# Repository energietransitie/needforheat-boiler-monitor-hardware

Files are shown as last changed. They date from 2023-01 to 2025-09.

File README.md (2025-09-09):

# NeedForHeat Boiler Monitor hardware <!-- omit in toc -->

This repository contains the open hardware design files for the NeedForHeat Boiler Monitor hardware, which consists of PCB and 3D printable pipeclamps for:

* Boiler-BASE module for the on the back of an [M5Stack CoreInk](https://docs.m5stack.com/en/core/coreink) device;
* Thermostat Cable Splitter module, which is inserted by the subject in the signal path between boiler and thermostat;
* Two pipe clamps with temperature sensors that can be clipped on the supply and return pipes that carry hot water from the boiler to the radiators and returning from the radiators.

This integrated device can:
* monitor OpenTherm signals between boiler and thermostat, similar to the [Twomes OpenTherm monitor](https://github.com/energietransitie/twomes-opentherm-monitor-hardware);
* monitor on/off signals between boiler and thermostat that do not adhere to the OpenTherm standard;
* monitor with supply and return water temperatures, similar to the [Twomes Temperature Monitor Hardware](https://github.com/energietransitie/twomes-temp-monitor-hardware).

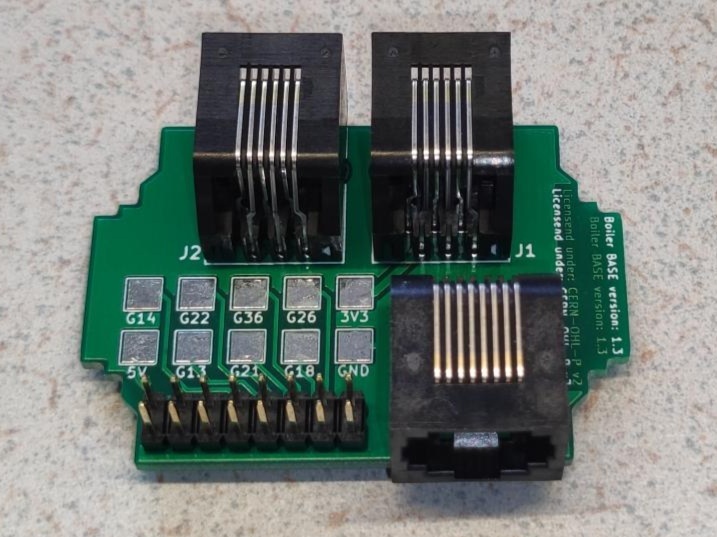
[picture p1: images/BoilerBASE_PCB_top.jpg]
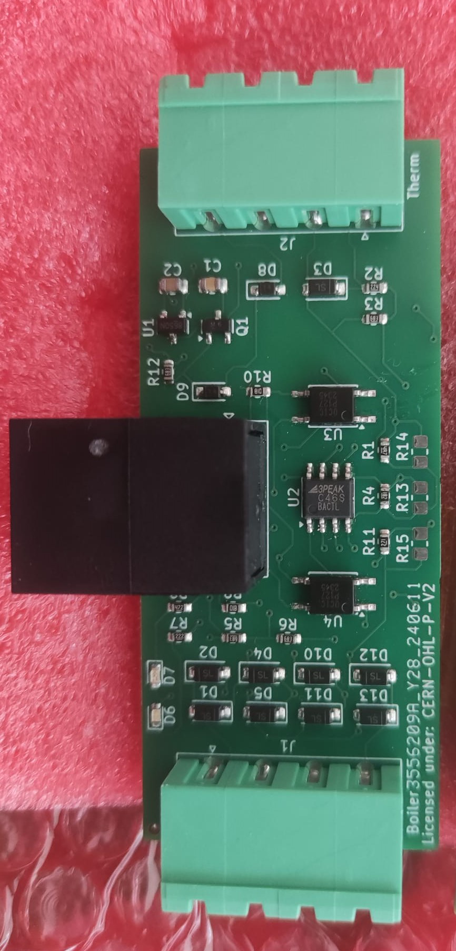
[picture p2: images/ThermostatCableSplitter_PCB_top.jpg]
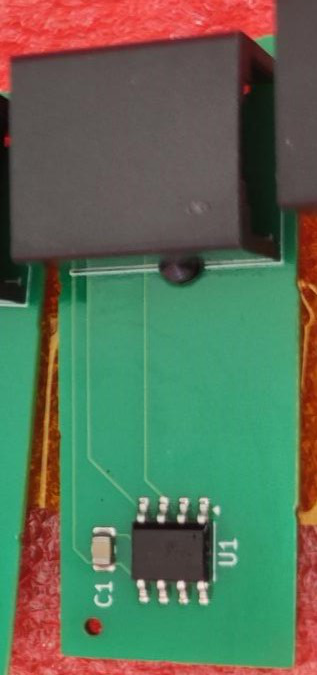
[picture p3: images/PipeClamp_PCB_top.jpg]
  

<!-- it would be better to have an image of the entire solution, including cables, like the assignment presentation -->

## Table of contents <!-- omit in toc -->
- [General info](#general-info)
- [Producing](#producing)
  - [Printed Circuit Board](#printed-circuit-board)
  - [Enclosures](#enclosures)
- [Deploying](#deploying)
  - [Cost](#cost)
  - [Connecting](#connecting)
  - [Disconnecting](#disconnecting)
- [Developing](#developing)
  - [Printed Circuit Board](#printed-circuit-board-1)
  - [Enclosures](#enclosures-1)
- [Features](#features)
- [Status](#status)
- [License](#license)
- [Citation](#citation)
- [Credits](#credits)

## General info
This repository contains the open hardware designs files and production files for the NeedForHeat Boiler Monitor. It also includes a `docs` folder with recent printouts of:
* BoilerBASE: [schematics](./docs/BoilerBase-sch.pdf) and [PCB layout](./docs/BoilerBase-pcb.pdf);
* Thermostat Cable Splitter:[schematics](./docs/ThermostatCableSplitter-sch.pdf) and [PCB layout](./docs/ThermostatCableSplitter-pcb.pdf);
* Pipe Clamps: [schematics](./docs/PipeClamp-pcb.pdf) and [PCB layout](./docs/PipeClamp-pcb.pdf).

The splitter features a 4 wire pluggable screw terminal on each side in which the cables can be connected to in almost any order.

The associated firmware that you need to run on this device was not yet implemented. I will be a combination of:
* [needforheat-generic-firmware](https://github.com/energietransitie/needforheat-generic-firmware) compiled with `env:M5STACK_COREINK`
* [twomes-opentherm-monitor-firmware](https://github.com/energietransitie/twomes-opentherm-monitor-firmware) 
* [twomes-boiler-base-firmware](https://github.com/energietransitie/twomes-boiler-base-firmware).

## Producing

### Printed Circuit Board
To manufacture the printed circuit board you can use various PCB services. 

The folder [pcb production](./pcb) includes all exported files needed to have the PCBs manufactured by [JLCPCB](https://www.jlcpcb.com). Upload a [zipped gerber file](./pcb/Gerber) to the [JLCPCB quote page](https://cart.jlcpcb.com/quote), select the amount of PCBs and a colour for the silkscreen. All other options can be left on default.

If you do not want to solder components on the PCB yourself, select `PCB assembly` and JLCPCB will do it for you (even for through-hole components if you so desire). This will take you to a page where the BOM and POS file can be uploaded. Use the files in [BOM-CPL](./pcb/BOM-CPL). 

JLCPCB provides detailed steps on their website to select component assembly, including wave soldering. For wave soldering or through-hole component assembly, specify this requirement when uploading your BOM and POS files. 

In the table below, you will find the files per PCB.

| PCB | zipped gerber | BOM | CPL | Components that do not need to be placed |
| --- | --- | --- | --- | --- |
| BoilerBASE | [GERBER-BoilerBASE.zip](pcb\BoilerBASE\jlcpcb\GERBER-BoilerBASE.zip) | [BOM-BoilerBASE.csv](pcb\BoilerBASE\jlcpcb\BoilerBASE\BOM-BoilerBASE.csv) | [BOM-BoilerBASE.csv](pcb\BoilerBASE\jlcpcb\BoilerBASE\CPL-BoilerBASE.csv) | |
| Thermostat Cable Splitter | [GERBER-ThermostatCableSplitter.zip](pcb\ThermostatCableSplitter\jlcpcb\GERBER-ThermostatCableSplitter.zip) | [BOM-ThermostatCableSplitter.csv](pcb\ThermostatCableSplitter\jlcpcb\ThermostatCableSplitter\BOM-ThermostatCableSplitter.csv) | [CPL-ThermostatCableSplitter.csv](pcb\jlcpcb\ThermostatCableSplitter\CPL-ThermostatCableSplitter.csv) | `R13`, `R14`, `R15` |
| Pipe Clamps | [GERBER-PipeClamp.zip](pcb\PipeClamp\jlcpcb\GERBER-PipeClamp.zip) | [BOM-PipeClamp.csv](pcb\PipeClamp\jlcpcb\Splitter\BOM-PipeClamp.csv) | [CPL-PipeClamp.csv](pcb\jlcpcb\Splitter\CPL-PipeClamp.csv) | |

### Enclosures

To manufacure the pipe clamps you can use your own 3D printer or use a 3D printing service. 

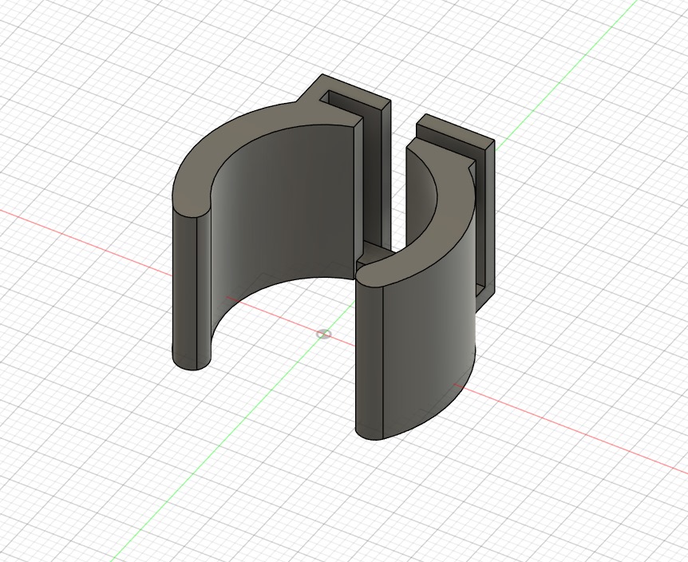
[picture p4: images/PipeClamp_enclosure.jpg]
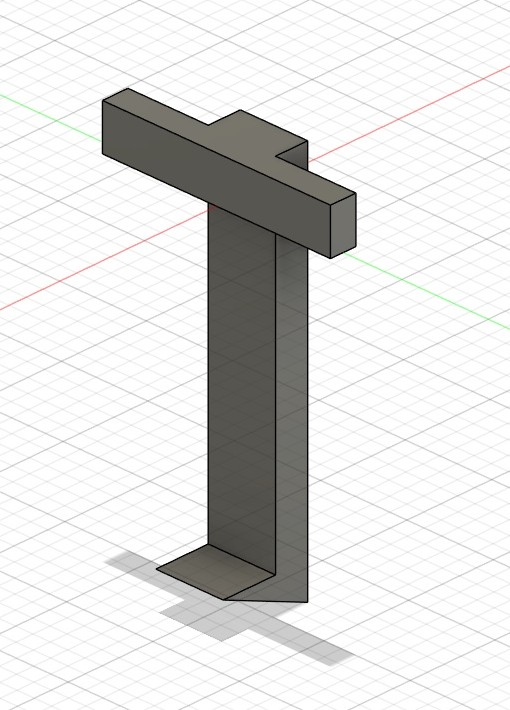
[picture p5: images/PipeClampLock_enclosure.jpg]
 

The folder [enclosure](./enclosure) contains exported STL files for:
* [Boiler-BASE enclosure](./enclosure/BoilerBASE/fabrication/BoilerBase.STL);
* [Pipe Clamp enclosure](./enclosure/PipeClamp/fabrication/PipeClamp.stl) and [Pipe Clamp enclosure locks](./enclosure/PipeClamp/fabrication/PipeClamp_lock.stl). 
 
The STL files can be imported into any slicer and turned into G-Code for a 3D printer.

We do not yet have designs for the Thermostata Cable Splitter.

## Deploying

### Cost
To deploy the NeedForHeat Boiler Module to a home, you need all hardware listed below. Prices indicate price per Boiler Monitor, based on ordering enough hardware for 10 Boiler Monitors, June 2024 including 21% VAT and shipping to an address in the Netherlands.

| # | Item | Supplier | Price per Unit | Subtotal | Shipping | Total |
| --- | --- | --- | ---: | ---: | ---: | ---: |
| 1 | BoilerBASE PCB | | €2.38 | €2.38 | €2.38 | €4,79 |
| 1 | BoilerBASE Enclosure | JLCPCB | €1.23 | €1.23 | €2.38 | €3.60 |
| 1 | Thermostat Cable Splitter PCB[^1] | JLCPCB | €5.02 | €5.02 | €3.23 | €8.25 |
| 1 | Thermostat Cable Splitter enclosure | | €2.38 | €2.38 | €2.38 | €4,79 |
| 2 | [Pluggable Terminal Blocks (5.08 mm. 4 ways)](https://nl.farnell.com/camdenboss/ctb9209-4/terminal-block-pluggable-4pos/dp/2493644) | | €1.15 | €2.30 | €1.82 | €3.12 |
| 2 | Pipe Clamp PCB | JLCPCB | €3.41 | €6.81 | €2.30 | €9.11 |
| 1 | Pipe Clamp enclosure | JLCPCB | €1.00 | €2.00 | €2.38 | €4.38 |
| 4 | [LEGO pen with friction](https://www.blokjeskoning.nl/product/pen-stroef-pen-stroef-zwart/) | Blokjeskoning | €0.03 | €0.12 | €0.30 | €0.42 |
| 1 | [M5Stack CoreInk](https://www.tinytronics.nl/nl/platformen-en-systemen/m5stack/e-paper/m5stack-m5core-ink-met-1.54-inch-e-paper-e-ink-display-esp32) | TinyTronics | €43.00 | €43.00 | €0.00 | €43.00 |
| 2 | [RJ12 cable (male-male; 6P6C; straight; 1 m)](https://www.allekabels.nl/rj12-kabel/7400/1181351/telefoonkabel-rj12.html) | AlleKabels | €3.08 | €6.16 | €0.13 | €6.29 |
| 1 | [RJ45 cable (male-male; 8P8C; straight; 1 m)](https://www.allekabels.nl/cat5e-kabel/15545/1098185/uutp-kabel-cat-5e.html) | AlleKabels | €1.29 | €1.29 | €0.13 | €1.42 |
| 1 | [USB-A 230V charger + USB-A to USB-C cable](https://www.allekabels.nl/usb-oplader/4508/3636716/usb-a-oplader-usb-c-kabel.html) | AlleKabels | €14.95 | €14.95 | €0.13 | €15.08 |
| | **TOTAL** | | | **€87.64** | **€17.46** | **€107.65** |

[^1]: Only the Thermostat Cable Splitter remains at the home of the user; the rest can be sent back after the measurement period.

### Connecting

Assuming that the PCBs are fully assembled, the devices have an enclosure, and the device has been programmed with the [needforheat-p1-reader-firmware](https://github.com/energietransitie/needforheat-p1-reader-firmware), you can proceed and connect the device as follows:

Tools needed;
- Screwdriver (flat head, 3 mm)
- Wire cutter
- Wire stripper

Steps:
1. **Unplug the power**
   - Unplug the boiler and thermostat from power outlets.

2. **Connect the Boiler Monitor**
   1. Cut the signal cable between the boiler and thermostat within 1.5 meters of a power outlet.
   2. Strip 2 cm of the outer sheath and 0.5 cm of insulation from each wire.
   3. Insert wires into the green pluggable screw terminal connectors and tighten screws.
   4. Attach connectors to the Thermostat Cable Splitter (boiler side: connector `J2` on the PCB and `CV` on the enclosure, thermostat side: connector `J1` on the PCB and  `T` on the enclosure).
   5. Connect the BoilerBASE to the M5Stack CoreInk MI-BUS using the 2x8 male pin header.
   6. Use an ethernet cable (RJ45) to connect the Thermostat Cable Splitter (connector `J3` on the PCB) to the BoilerBASE (connector `J3` on the PCB).
   7. Power the M5Coreink+BoilerBASE via USB-C.
   8. Insert PipeClamp PCBs into enclosures and secure with locking pins.
   9. Use cables (RJ12) to connect the BoilerBASE (connector `J1` and `J2` on the PCB; order does not matter) to the PipeClamps (connector `J1` on the PCB).
   10. Attach the M5Coreink+BoilerBASE to the boiler with its magnetic back on a flat metal surface of the boiler.
   11. Check LEDs on the Thermostat Cable Splitter; if not blinking, switch wires 1 & 2 or 3 & 4 in the pluggable screw connector on the thermostat side.

3. **Plug the power back in**
   - Reconnect the boiler and thermostat to power outlets.

### Disconnecting

After the measurement period, the user only needs to unplug the RJ45 cable from the Thermostat Cable Splitter, which can remain connected with the thermostat cable in the user's home. The rest can be sent back and re-used in other homes. 

## Developing

### Printed Circuit Board

To change the hardware design of the PCBs, you need:
* [KiCad version 8.0.0 or later](https://www.kicad.org/download/) installed to change te PCB design. 

The KiCad source files of the PCB can be found in subfolders of the folder [pcb](./pcb):
* [BoilerBASE](./pcb/BoilerBASE/)
* [ThermostatCableSplitter](./pcb/ThermostatCableSplitter/)
* [PipeClamp](./pcb/PipeClamp/)

To convert the PCBs into a format suitable for fabrication, consult the webpage of your PCB manufacturer of choice. For example, see the [JLCPCB guide on how to export Gerbers](https://support.jlcpcb.com/article/149-how-to-generate-gerber-and-drill-files-in-kicad) and the  [JLCPCB guide how to export the BOM and POS files](https://support.jlcpcb.com/article/84-how-to-generate-the-bom-and-centroid-file-from-kicad). You may also use a KiCad plug-in for this purpose such as [kicad-jlcpcb-tools](https://github.com/Bouni/kicad-jlcpcb-tools).

### Enclosures
To change the hardware design of an enclosure, you need either:
* [Autodesk Fusion 360]([https://www.kicad.org/download/](https://www.autodesk.com/products/fusion-360/personal)) installed (Autodesk provides 30 day free trials and [free one-year educational access](https://www.autodesk.com/education/edu-software/overview?sorting=featured&filters=individual) to its products and services for eligible students, teachers and research staff); 
* or [FreeCAD](https://www.freecadweb.org/), an open source alternative.

The source files of the enclosures can be found in subfolders of the folder [enclosure](./enclosure):
* [BoilerBASE](./enclosure/BoilerBASE)
* ThermostatCableSplitter (*We do not yet have a design for this enclosure*)
* [PipeClamp](./enclosure/PipeClamp/)

## Features
The  NeedForHeat Boiler Monitor features the follwoing main hardware components:
- [x] Thermostat Cable Splitter PCB with 4-wire pluggable screw terminals and circuit to monitor OpenTherm communication, including LEDs and optocouplers;
- [x] Circuit in the Thermostat Cable Splitter that allows (mostly) order agnostic connection of the 4 wires per pluggable screw connector (see also [connecting the devices](#connecting-the-devices));
- [x] Pipe Clamp PCB to measure temperatures from the supply and return pipes below the boiler.
- [x] Pipe Clamp enclosures, which can be 3D printed as a clamp that presses the temperature sensors agains a water pipe below a heating boiler and provide a  locking mechanism the prevent the PCB from falling out.

To-do:
- Thermostat Cable Splitter
  - [ ] Reconsider the choice of pluggable screw connectors: reversible? lever-operated (e.g., [WAGO PCB terminal block](https://www.wago.com/global/c/pcb-terminal-blocks-and-pluggable-connectors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))?
  - [ ] Redesign the thermostat side such that the user can mount the wires truly in any order.
  - [ ] Design an enclosure.
* BoilerBASE
  - [ ] Add an 868 MHz SMD transceiver chip to enable monitoring of wireless thermostats.
  - [ ] Add connectors to BOM and CPL files and repair rotation errors to enable through-hole soldering by JLCPC.
  - [ ] Evaluate relocating the 2x8 pin header from the bottom side to the top side of the PCB to reduce JLCPCB manufacturing costs. 
  - [ ] Improve BOM and CPL for JLCPCB through hole assembly. 
  - [ ] Design an enclosure that adds multiple mounting options
    - [ ] room to embed permanent magnets to make it stick to flat metallic surfaces of boilers;
    - [ ] a tie wrap hole.
* Pipe Clamps
  - [ ] Redesign 3D printed enclosures to ensure strength and durability.

## Status
Project is:  _in_progress_

## License
The hardware designs in this repository are available under the [CERN-OHL-P v2 license](./LICENSE), Copyright 2024 [Research group Energy Transition, Windesheim University of Applied Sciences](https://windesheim.nl/energietransitie)

## Citation

If you use this repository in your research or work, please cite the following pre-print, which describes the overall NeedForHeat DataGear system of which this repository is a part:

> Ter Hofte, H., & van Ravenzwaaij, N. (2025). *NeedForHeat DataGear: An Open Monitoring System to Accelerate the Residential Heating Transition*. arXiv preprint arXiv:2509.06927. https://doi.org/10.48550/arXiv.2509.06927

**Note:** This is a pre-print submitted on 8 Sep 2025 and has not yet been peer-reviewed. For the full paper, see [https://arxiv.org/abs/2509.06927](https://arxiv.org/abs/2509.06927).

## Credits
This hardware is a collaborative effort of:
* Bram Busch · [@BlueRisen](https://github.com/BlueRisen)
* Daan Tellegen · [@D-Tellegen](https://github.com/D-Tellegen)

Earlier versions of this open hardware were designed by:
* Huub Buter · [@h-buter](https://github.com/h-buter>)
* Mirjam van Wee
* Kees Fokker
  
Product owners:
* Henri ter Hofte · [@henriterhofte](https://github.com/henriterhofte)
* Marco Winkelman · [@MarcoW71](https://github.com/MarcoW71)

We use and gratefully acknowlegde the efforts of the makers of the following designs:

* [Twomes OpenTherm monitor](https://github.com/energietransitie/twomes-opentherm-monitor-hardware), by Research group Energy Transition at Windesheim University of Applied Sciences, licenced under [Apache 2.0](https://raw.githubusercontent.com/energietransitie/twomes-opentherm-monitor-hardware/main/LICENSE)
* [Twomes Temperature Monitor Hardware](https://github.com/energietransitie/twomes-temp-monitor-hardware), by Research group Energy Transition at Windesheim University of Applied Sciences, licenced under [Apache 2.0](https://raw.githubusercontent.com/energietransitie/twomes-temp-monitor-hardware/main/LICENSE)
* [KiCad Libraries](https://kicad.github.io/), by the KiCad Development Team, licensed under [an adapted version of the CC-BY-SA 4.0 License](https://www.kicad.org/libraries/license/)

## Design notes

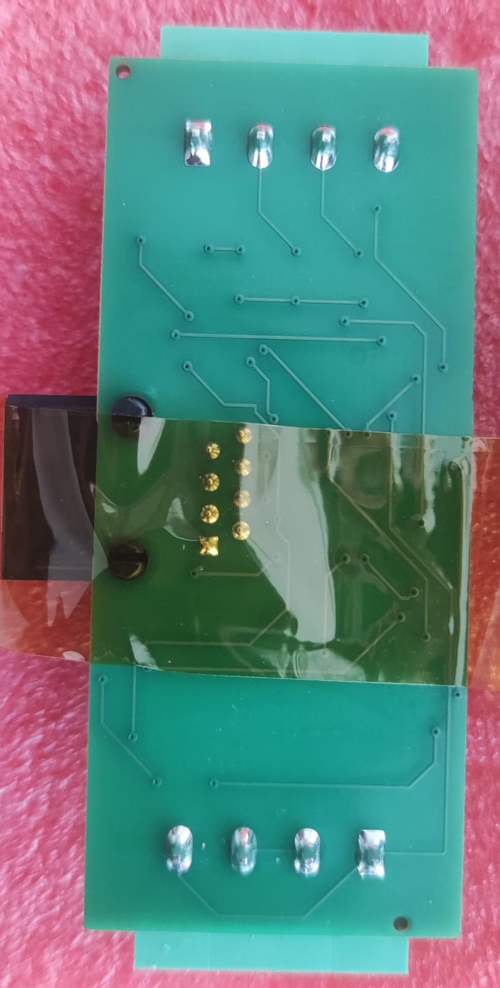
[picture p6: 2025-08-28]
images/ThermostatCableSplitter_PCB_bottom.jpg

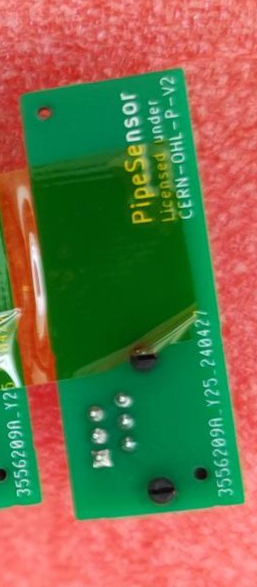
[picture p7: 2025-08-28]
images/PipeClamp_PCB_bottom.jpg

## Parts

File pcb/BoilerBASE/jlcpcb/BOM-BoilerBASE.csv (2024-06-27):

Designator | Footprint | Quantity | Value | LCSC Part #
J1 | RJ11 | 1 | Temp-1
J2 | RJ11 | 1 | Temp-2
J3 | RJ45-TE-connectivity | 1 | OpenThermMonitor
J5 | PinHeader_2x08_P2.54mm_Vertical | 1 | M5stack-MI-bus
R1, R2 | R_0805_2012Metric_Pad1.20x1.40mm_HandSolder | 2 | 4k7

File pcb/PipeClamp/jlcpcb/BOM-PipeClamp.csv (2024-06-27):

Comment | Designator | Footprint | LCSC
100nF | C1 | C_0805_2012Metric | C49678
DS18B20Z | U1 | SOIC-8_3.9x4.9mm_P1.27mm | C695837
RJ12 | J1 | RJ25_Wayconn_MJEA-660X1_Horizontal | C77859

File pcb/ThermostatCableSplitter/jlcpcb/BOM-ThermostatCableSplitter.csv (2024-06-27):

Comment | Designator | Footprint | LCSC
10uF | C2 | C_0805_2012Metric | C15850
1k | R10,R9 | R_0603_1608Metric | C21190
1N4148WS | D8,D9 | D_SOD-323_HandSoldering | C2128
Transistor | Q1 | SOT-23 | C2149
220k | R2 | R_0603_1608Metric | C22961
270 | R11 | R_0603_1608Metric | C22966
4.7k | R8 | R_0603_1608Metric | C23162
4.7 | R1 | R_0603_1608Metric | C23164
68k | R12,R3,R5,R6 | R_0603_1608Metric | C23231
100nF | C1 | C_0805_2012Metric | C28233
CYTLP127(TP) | U3,U4 | SO-4_4.4x3.6mm_P2.54mm | C2836429
Blue Therm (Voltage) | D6 | LED_0603_1608Metric | C2986058
1.8K | R4 | R_0603_1608Metric | C4177
2.2k | R7 | R_0603_1608Metric | C4190
SE8650X2-HF | U1 | SOT-23 | C496615
Yellow Boiler (Current) | D7 | LED_0603_1608Metric | C72038
Boiler | J1,J2 | PhoenixContact_MSTBA_2,5_4-G-5,08_1x04_P5.08mm_Horizontal | C8446
B5819W SL | D1,D10,D11,D12,D13,D2,D3,D4,D5 | D_SOD-123 | C8598
RJ45 | J3 | RJ45_Amphenol_54602-x08_Horizontal | C86577
LMV393TP-SR | U2 | SOIC-8_3.9x4.9mm_P1.27mm | C97672
TBD | R14 | R_0805_2012Metric_Pad1.20x1.40mm_HandSolder
TBD | R15 | R_0805_2012Metric_Pad1.20x1.40mm_HandSolder
TBD | R13 | R_0805_2012Metric_Pad1.20x1.40mm_HandSolder

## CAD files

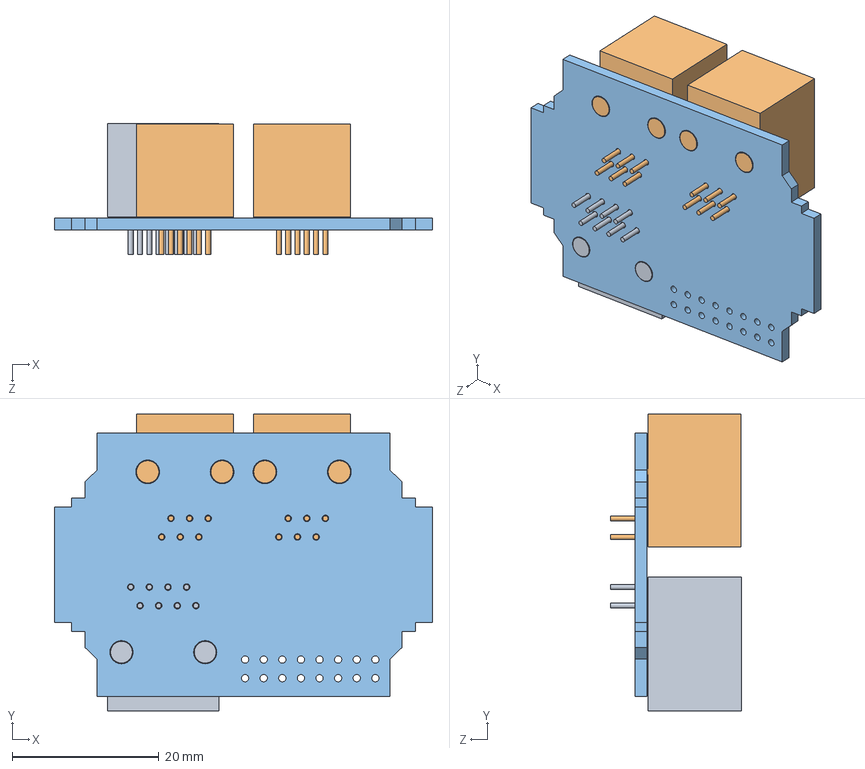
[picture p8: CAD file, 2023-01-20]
enclosure/BoilerBASE/Solidworks/IO-Base-PCB-Mouser.SLDASM
51.6 x 40.5 x 17.8 mm
COMPOUND.STEP
COMPOUND-0.STEP x 2
IO-Base-mouser PCB.STEP

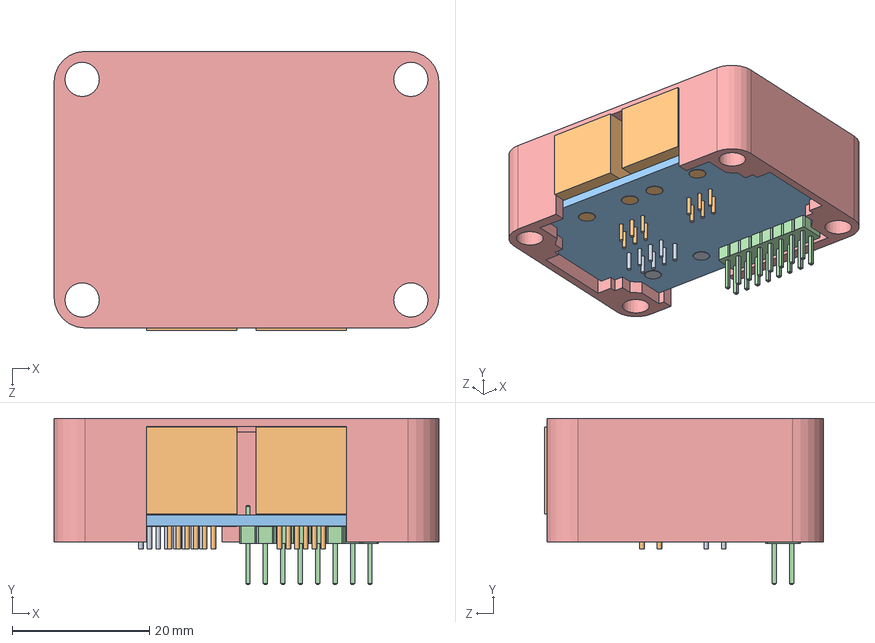
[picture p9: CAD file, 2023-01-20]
enclosure/BoilerBASE/Solidworks/Assembly.SLDASM
56.1 x 24.2 x 40.7 mm
COMPOUND.STEP
COMPOUND-0.STEP x 2
IO-Base-mouser PCB.STEP
PinHeader_2x08_P2.54mm_Vertical
case

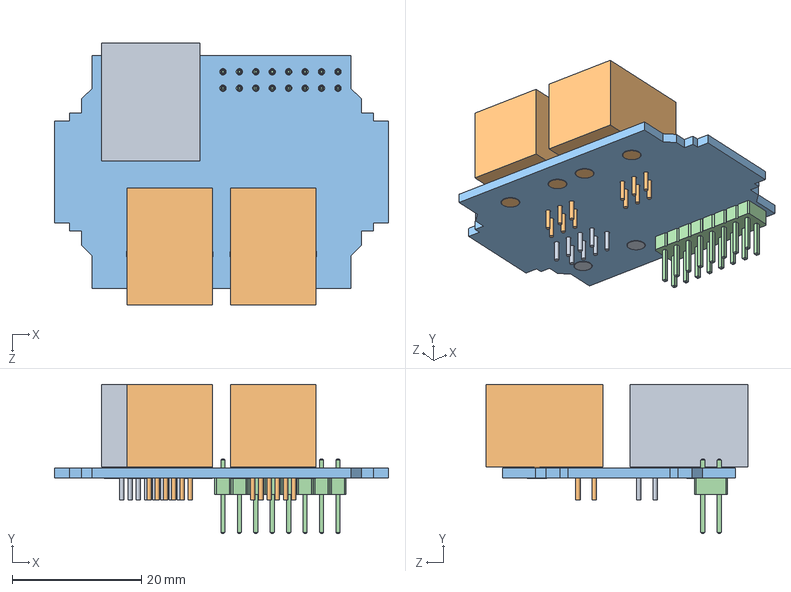
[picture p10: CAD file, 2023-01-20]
enclosure/BoilerBASE/Solidworks/IO-Base-PCB-Mouser-Assembly.SLDASM
51.6 x 23.0 x 40.5 mm
COMPOUND.STEP
COMPOUND-0.STEP x 2
IO-Base-mouser PCB.STEP
PinHeader_2x08_P2.54mm_Vertical

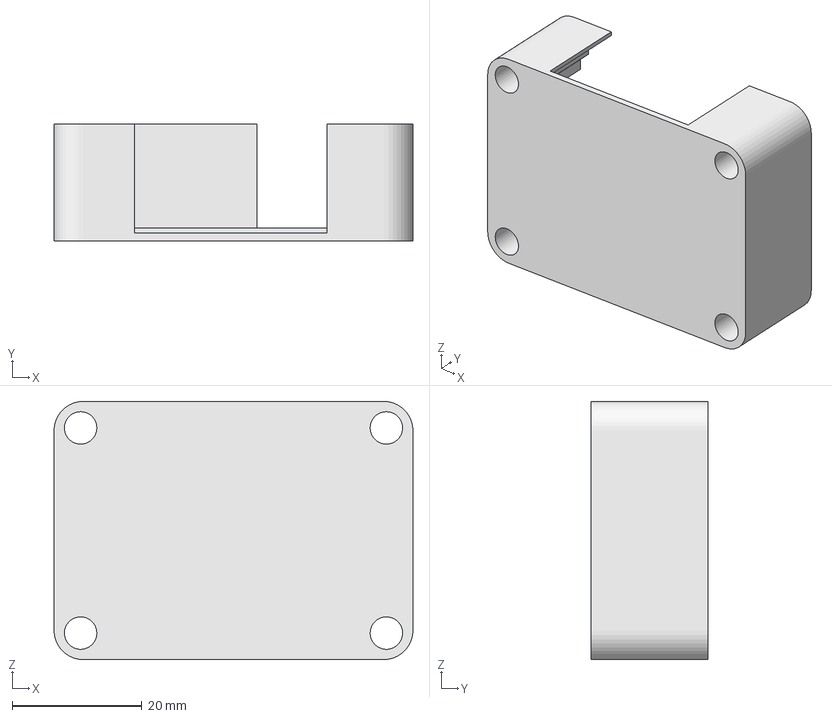
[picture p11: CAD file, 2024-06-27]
enclosure/BoilerBASE/BoilerBASE.FCStd
55.3 x 18.0 x 39.8 mm

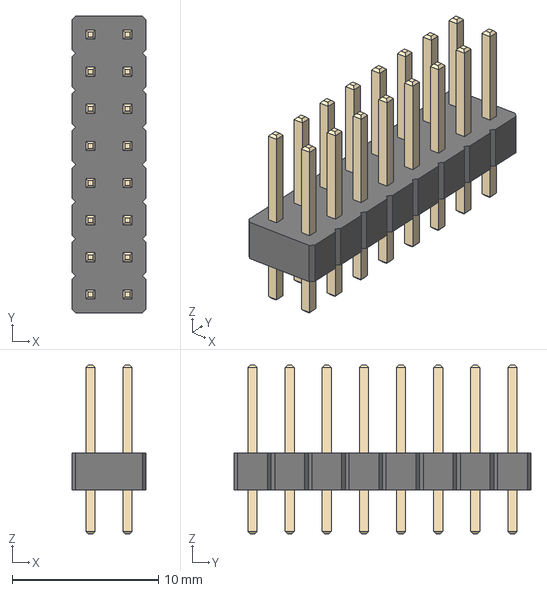
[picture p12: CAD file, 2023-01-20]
enclosure/BoilerBASE/Solidworks/PinHeader_2x08_P2.54mm_Vertical.step
5.08 x 20.3 x 11.5 mm

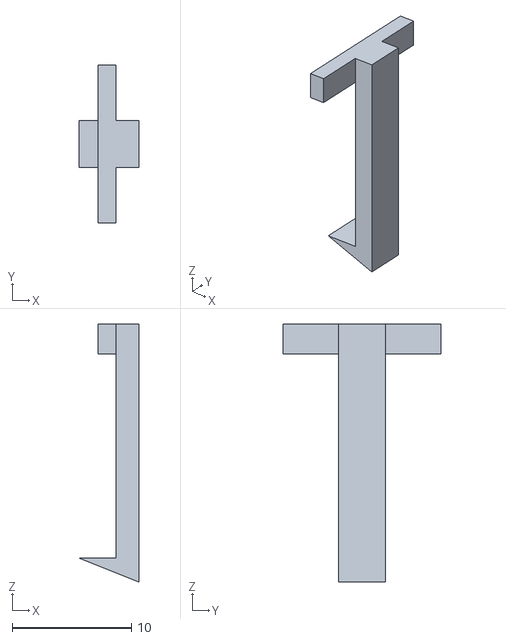
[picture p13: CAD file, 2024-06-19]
enclosure/PipeClamp/fabrication/Pipeclamp_lock.stl
5.00 x 13.2 x 21.6

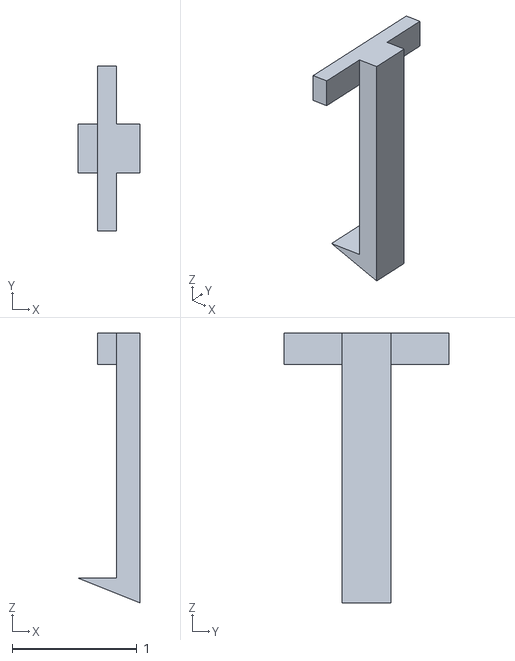
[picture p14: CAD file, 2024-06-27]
enclosure/PipeClamp/Pipeclamp lock.obj
0.5 x 1.32 x 2.16

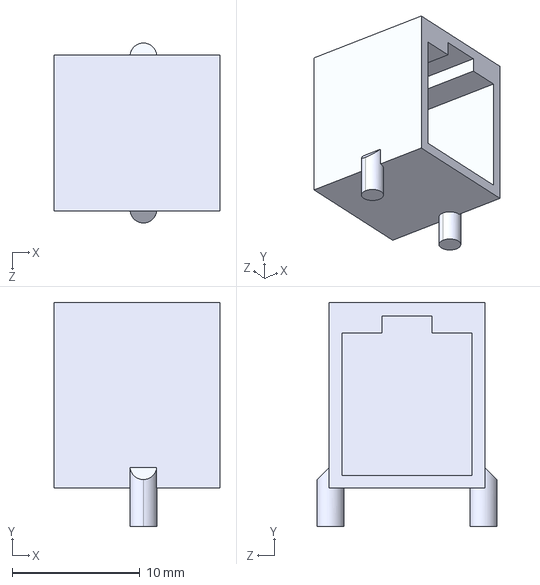
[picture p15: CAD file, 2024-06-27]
pcb/BoilerBASE/3D-models/RJ11.STEP
13.0 x 17.6 x 14.1 mm

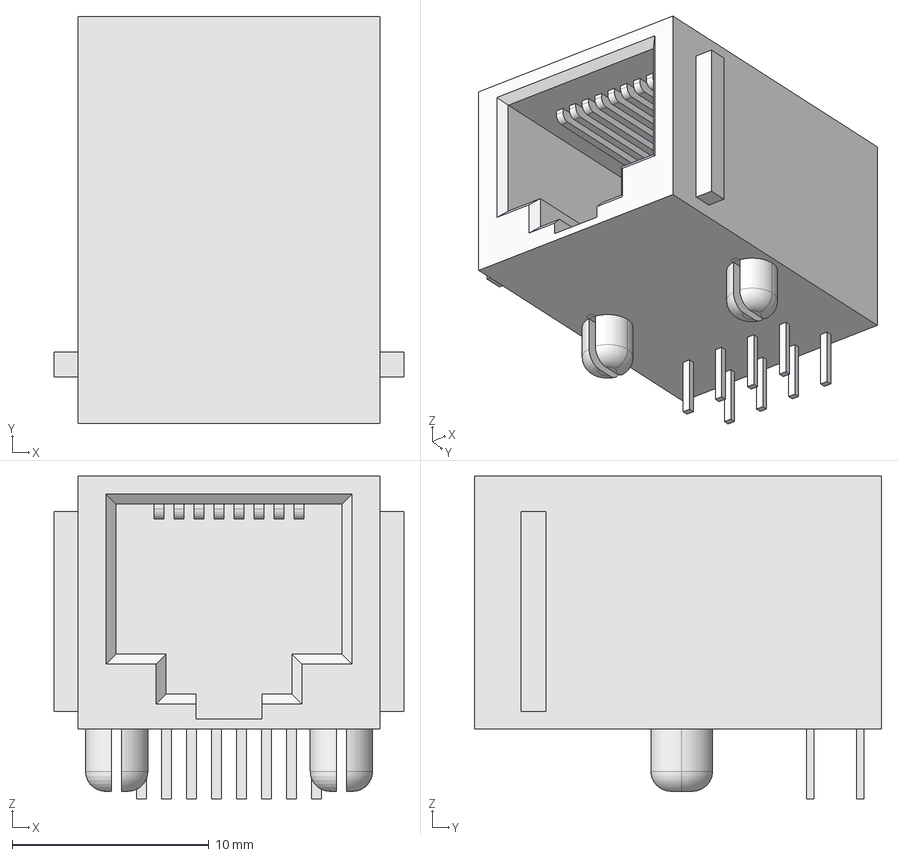
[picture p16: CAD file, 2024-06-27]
pcb/ThermostatCableSplitter/RJ45_SS_6488_FLS_Stewart.step
17.8 x 20.7 x 16.4 mm

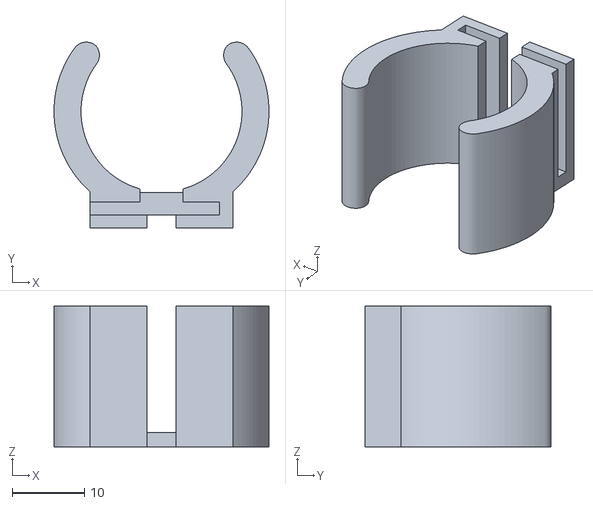
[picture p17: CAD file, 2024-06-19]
enclosure/PipeClamp/fabrication/Pipeclamp.stl
29.8 x 25.7 x 19.5

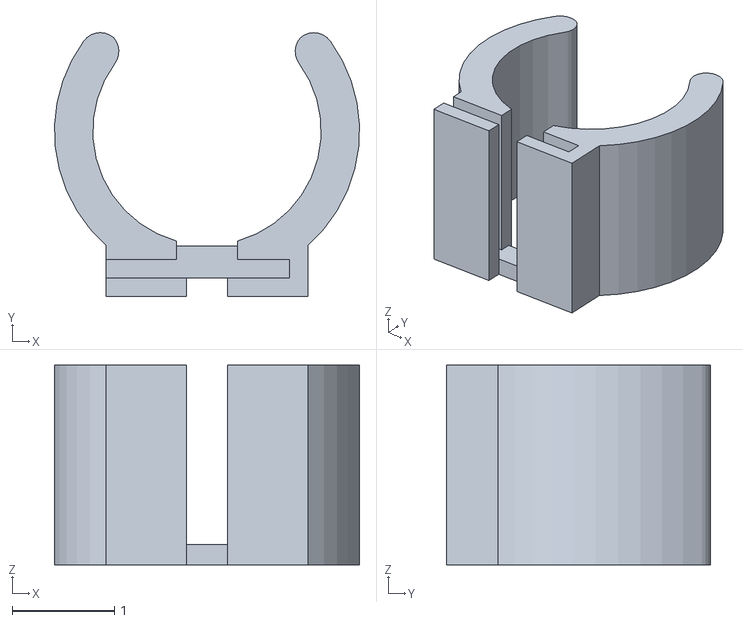
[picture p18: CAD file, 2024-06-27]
enclosure/PipeClamp/Pipeclamp_.obj
2.98 x 2.58 x 1.95

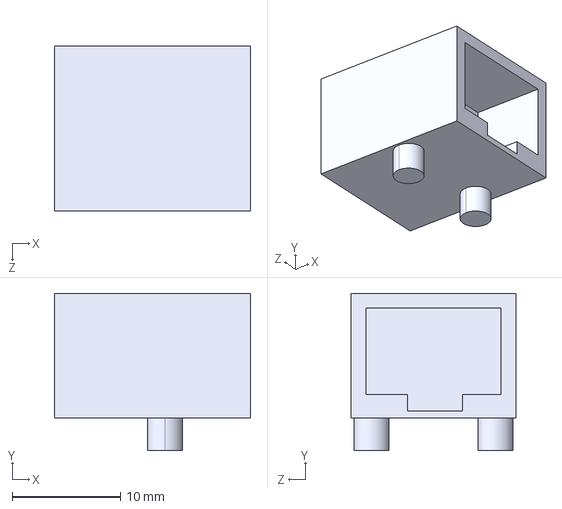
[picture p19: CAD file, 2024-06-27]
pcb/BoilerBASE/3D-models/RJ45.STEP
18.1 x 14.5 x 15.2 mm

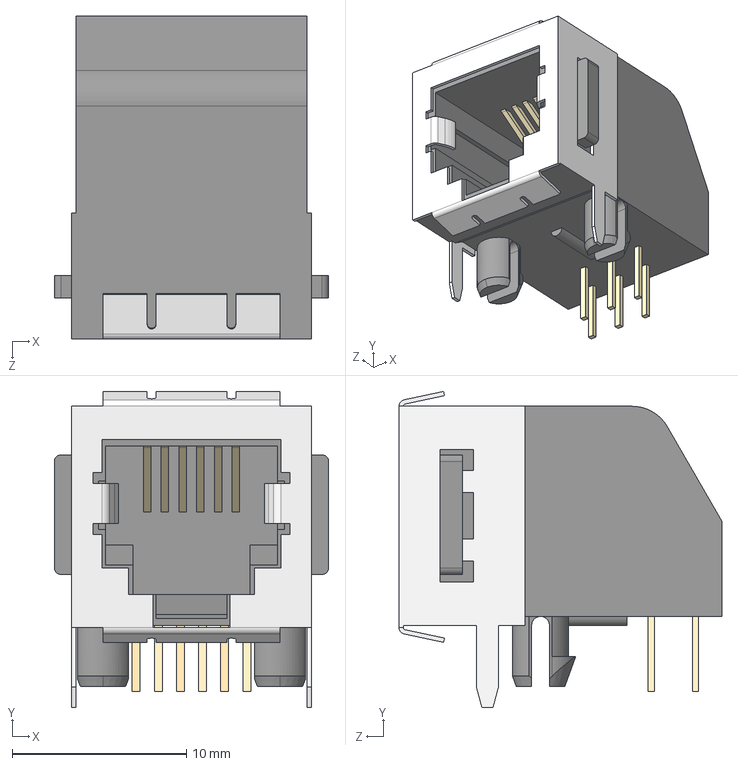
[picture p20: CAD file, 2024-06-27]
pcb/PipeClamp/3D-Models/c-5555140-1-e-3d.stp
15.7 x 18.1 x 18.5 mm

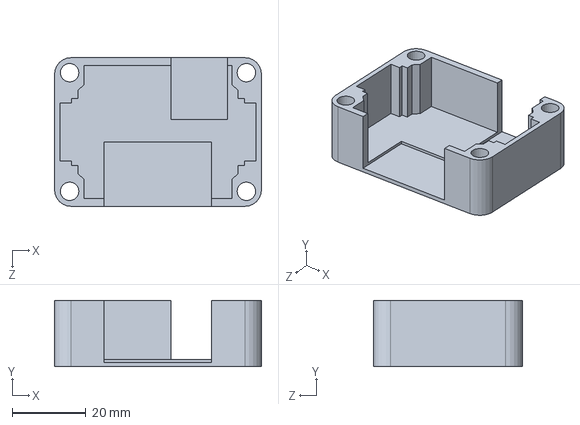
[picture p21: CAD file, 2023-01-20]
enclosure/BoilerBASE/Solidworks/case.SLDPRT
56.1 x 18.0 x 40.3 mm

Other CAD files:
enclosure/BoilerBASE/fabrication/BoilerBase.STL
enclosure/BoilerBASE/Solidworks/IO-Base-Mouser.STEP
enclosure/BoilerBASE/Solidworks/PinHeader_2x08_P2.54mm_Vertical.SLDPRT
pcb/PipeClamp/3D-Models/RJ11.SLDPRT

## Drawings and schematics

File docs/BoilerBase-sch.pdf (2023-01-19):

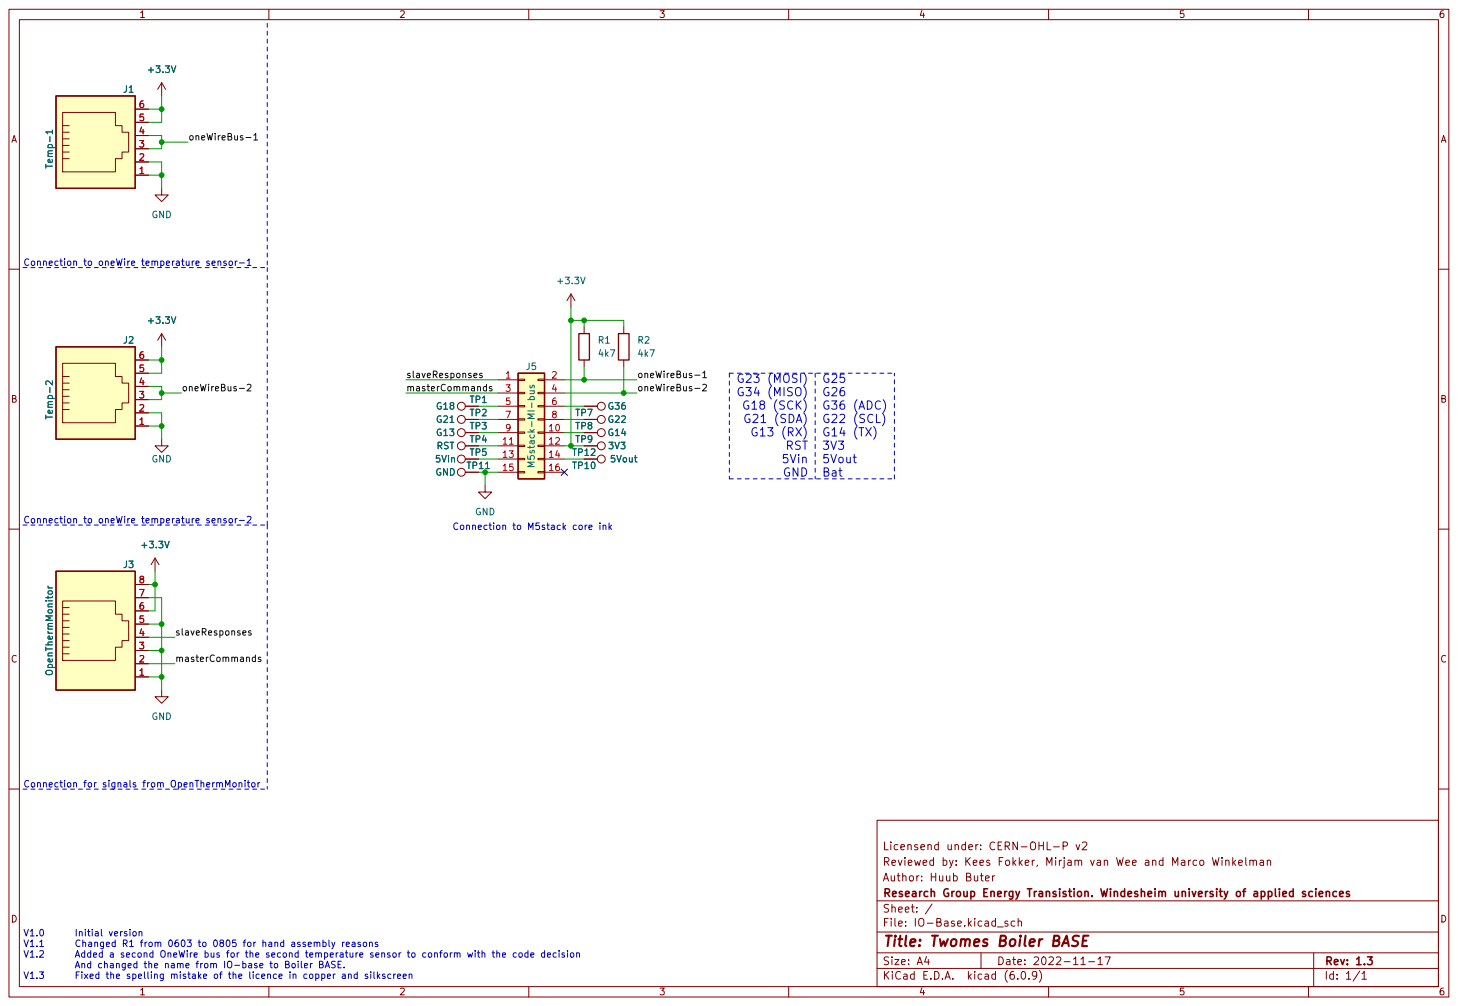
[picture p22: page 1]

Connection to oneWire temperature sensor-2

Connection for signals from OpenThermMonitor V1.0 Initial version V1.1 Changed R1 from 0603 to 0805 for hand assembly reasons

Licensend under: CERN-OHL-P v2
File: IO-Base.kicad_sch Sheet: / Research Group Energy Transistion. Windesheim university of applied sciences Author: Huub Buter Reviewed by: Kees Fokker, Mirjam van Wee and Marco Winkelman

Id: 1/1 Title: Twomes Boiler BASE

V1.2 Added a second OneWire bus for the second temperature sensor to conform with the code decision
And changed the name from IO-base to Boiler BASE.
V1.3 Fixed the spelling mistake of the licence in copper and silkscreen

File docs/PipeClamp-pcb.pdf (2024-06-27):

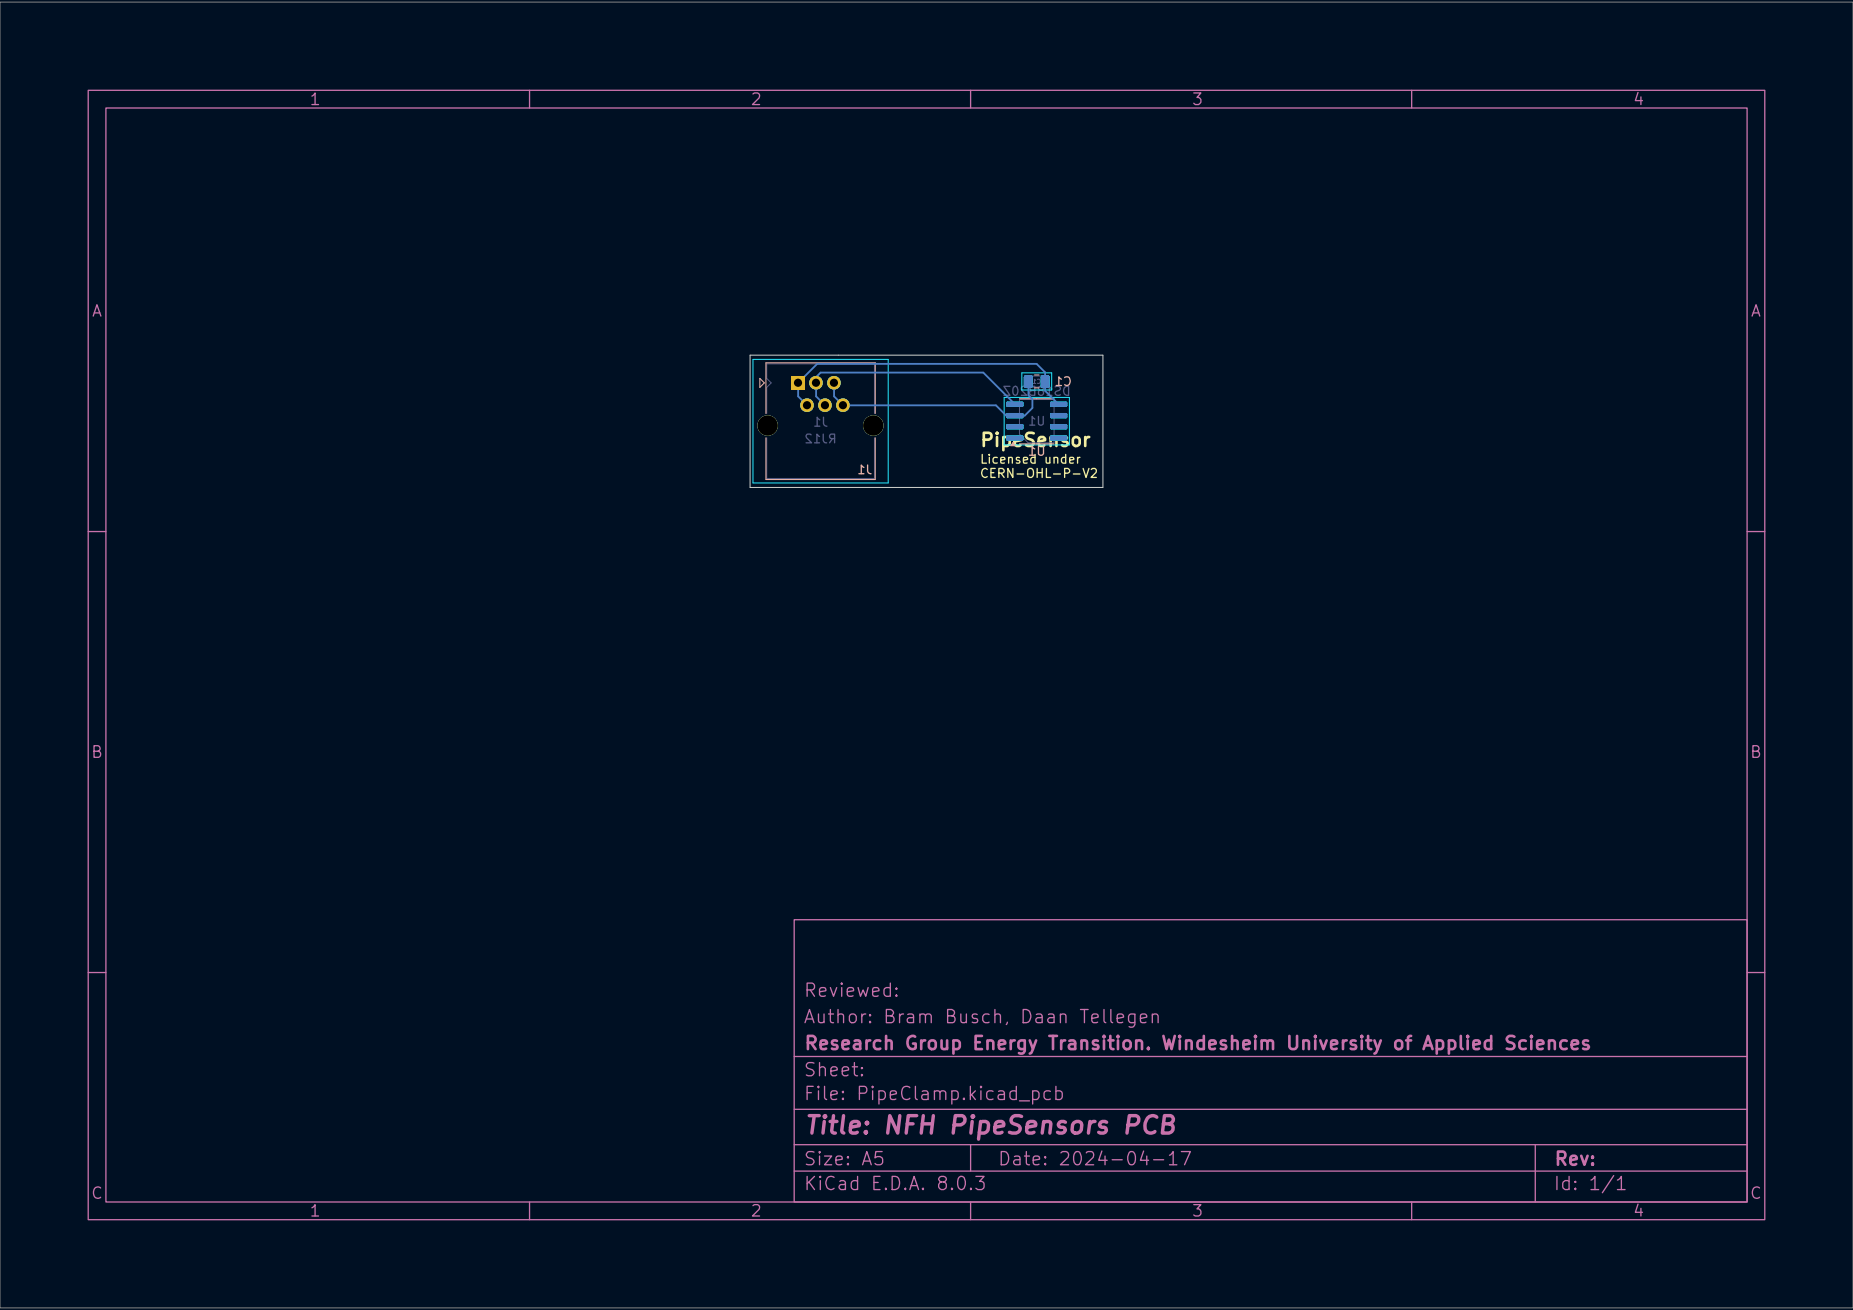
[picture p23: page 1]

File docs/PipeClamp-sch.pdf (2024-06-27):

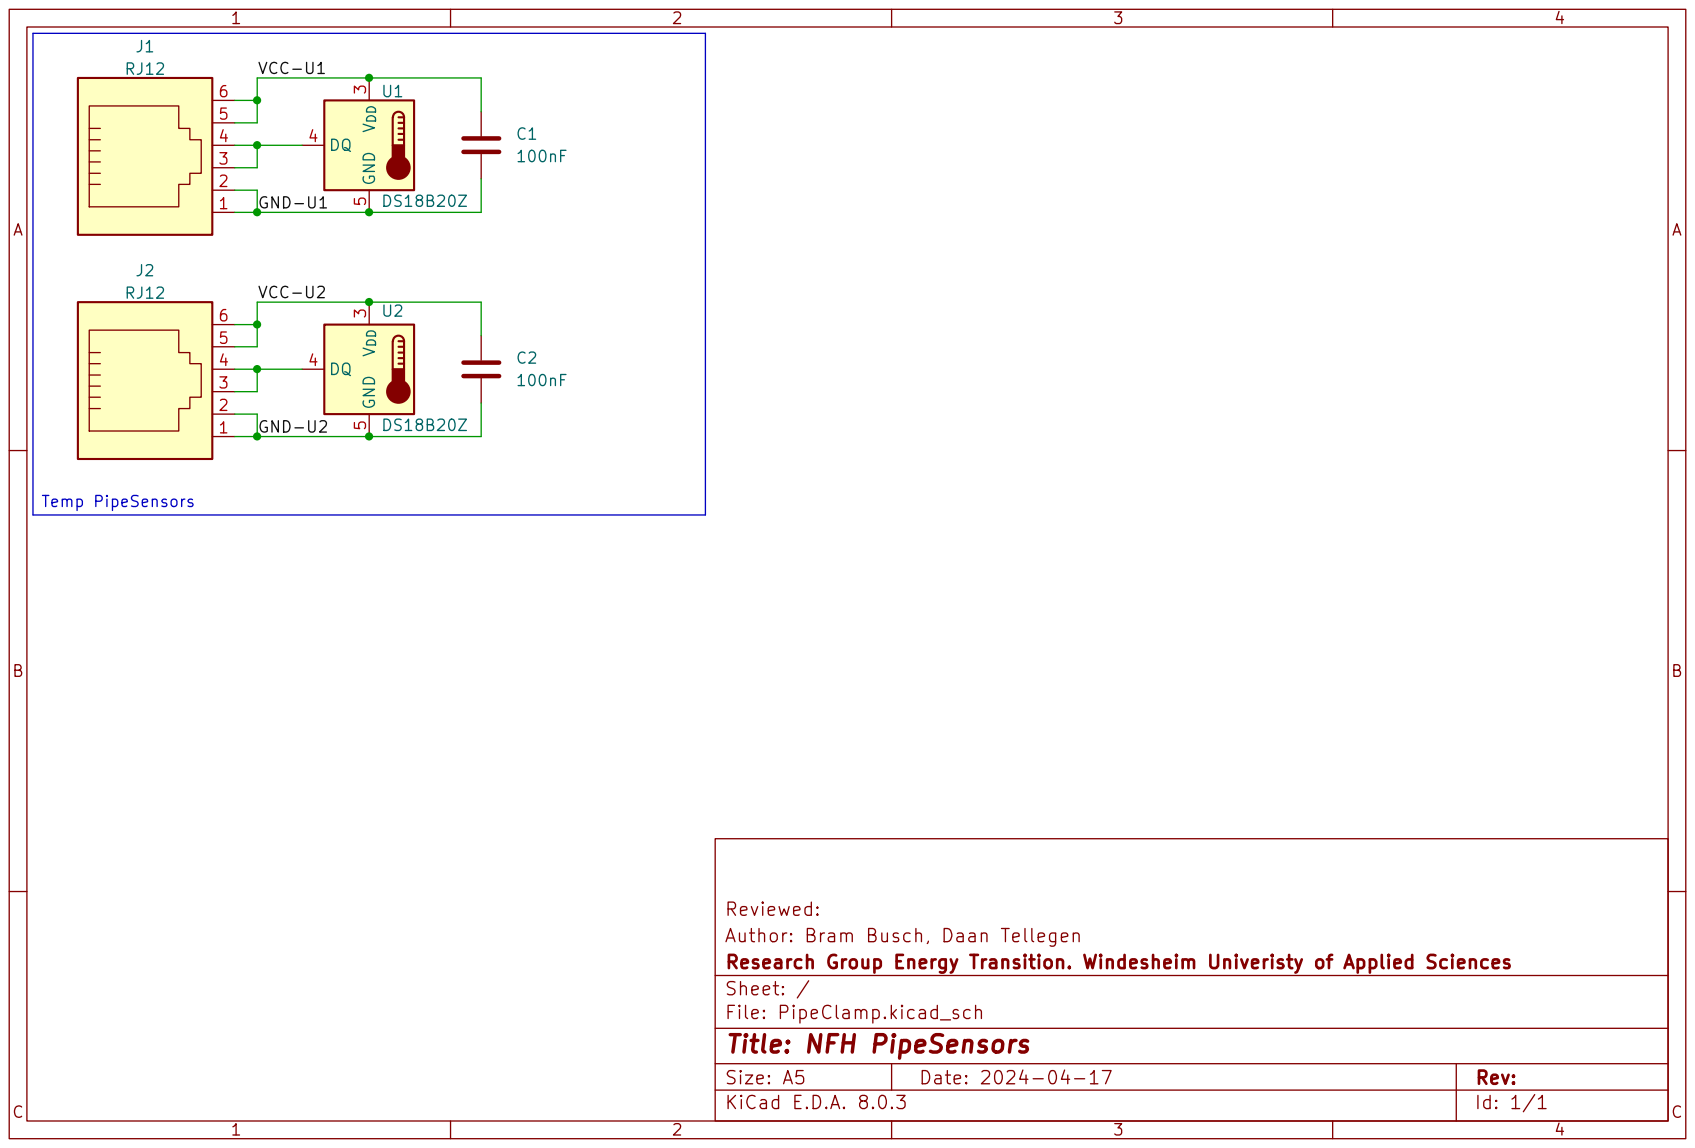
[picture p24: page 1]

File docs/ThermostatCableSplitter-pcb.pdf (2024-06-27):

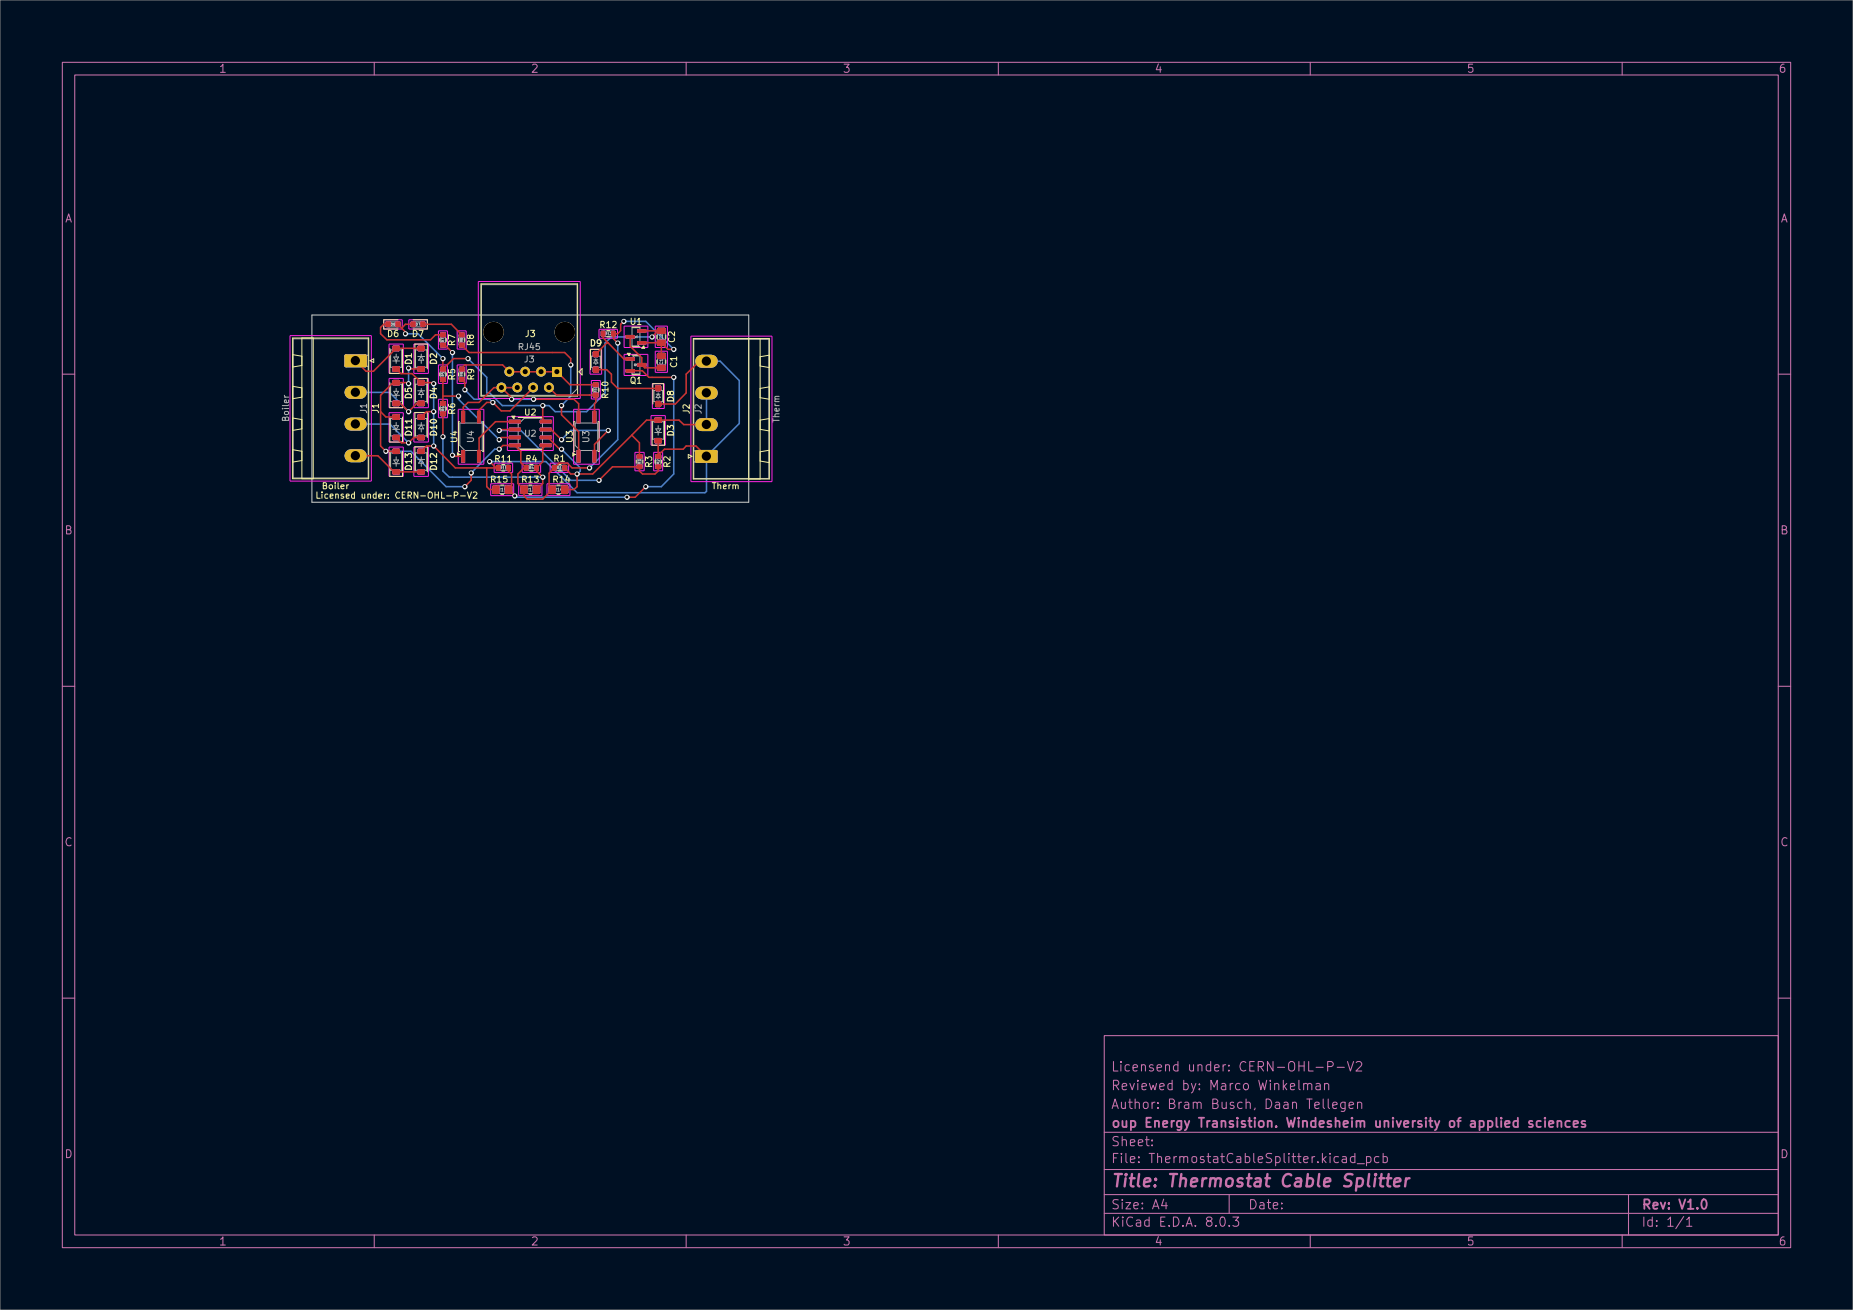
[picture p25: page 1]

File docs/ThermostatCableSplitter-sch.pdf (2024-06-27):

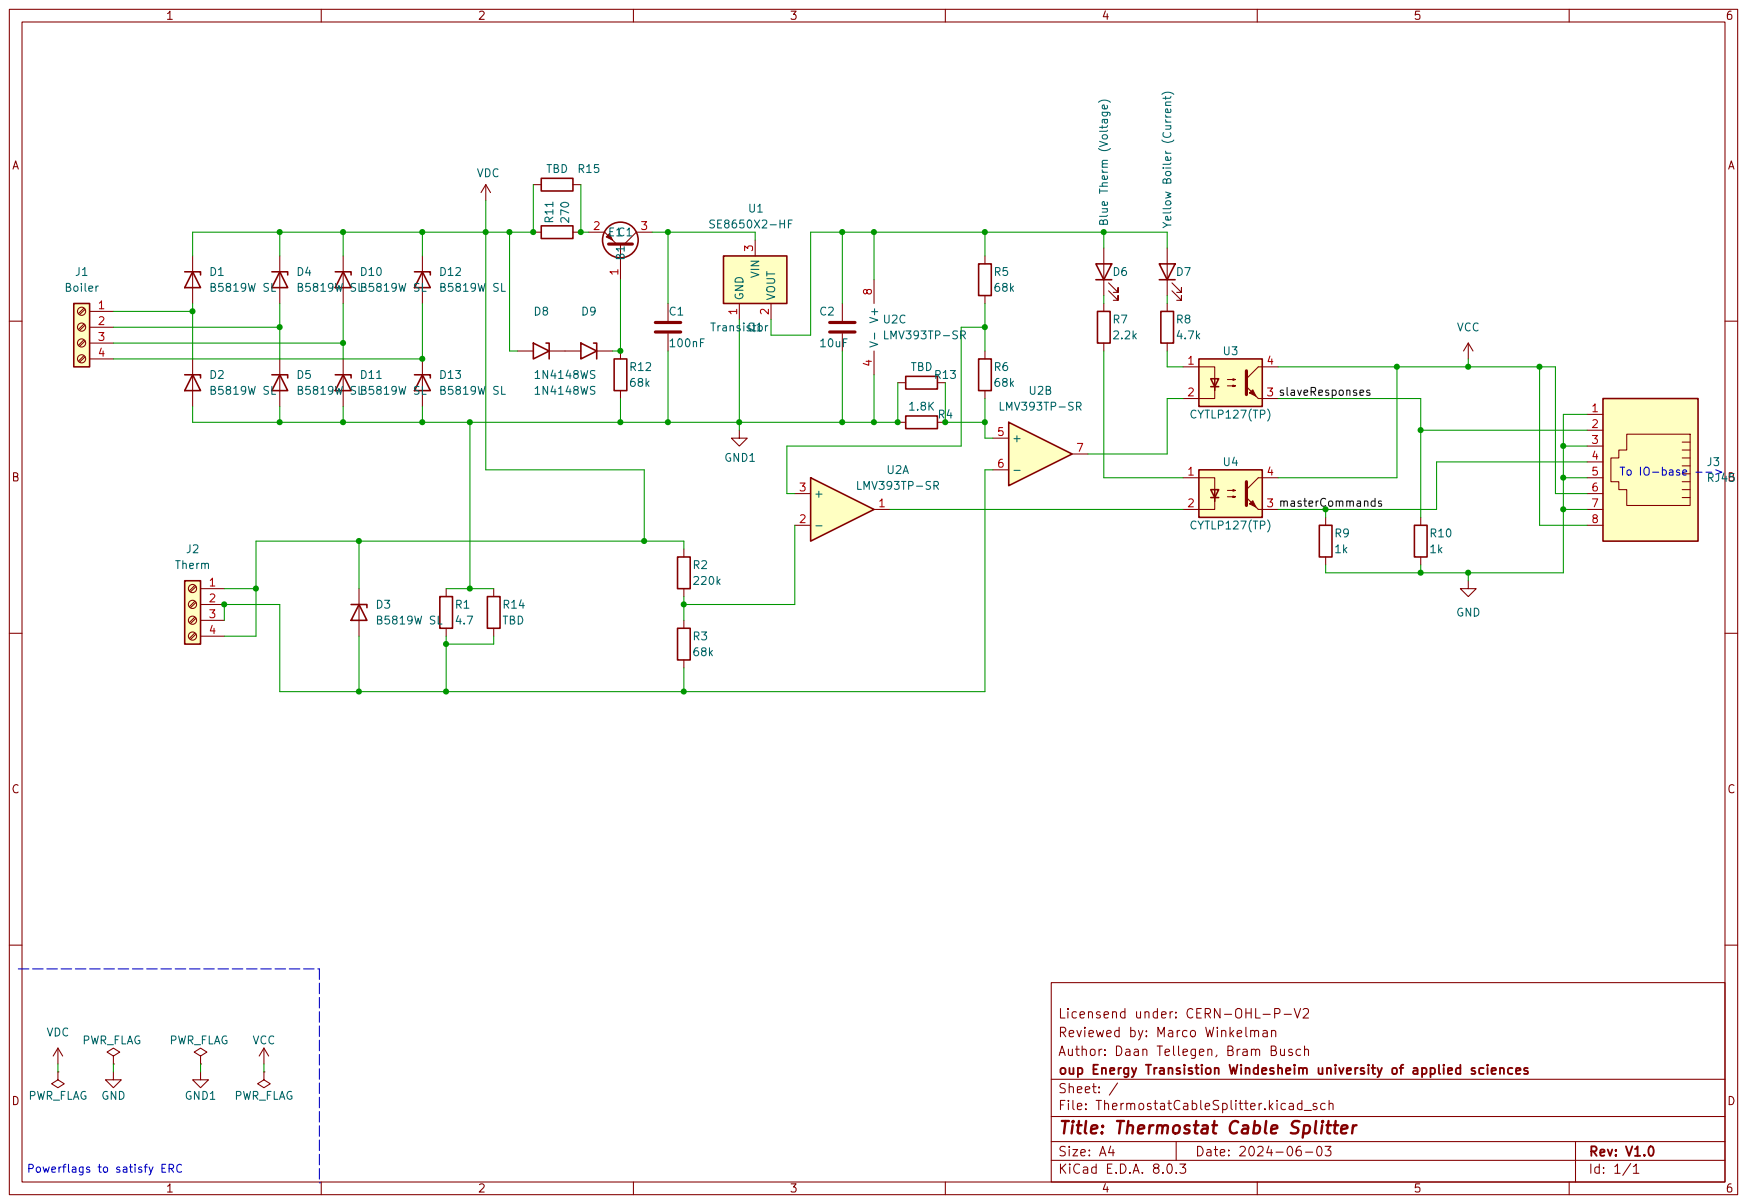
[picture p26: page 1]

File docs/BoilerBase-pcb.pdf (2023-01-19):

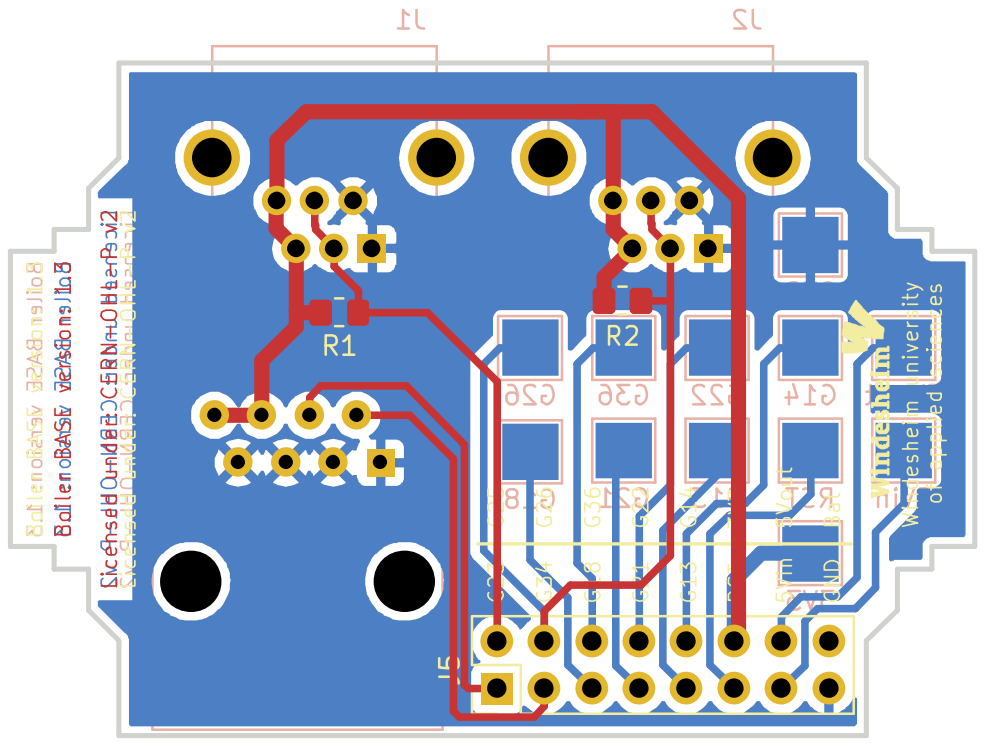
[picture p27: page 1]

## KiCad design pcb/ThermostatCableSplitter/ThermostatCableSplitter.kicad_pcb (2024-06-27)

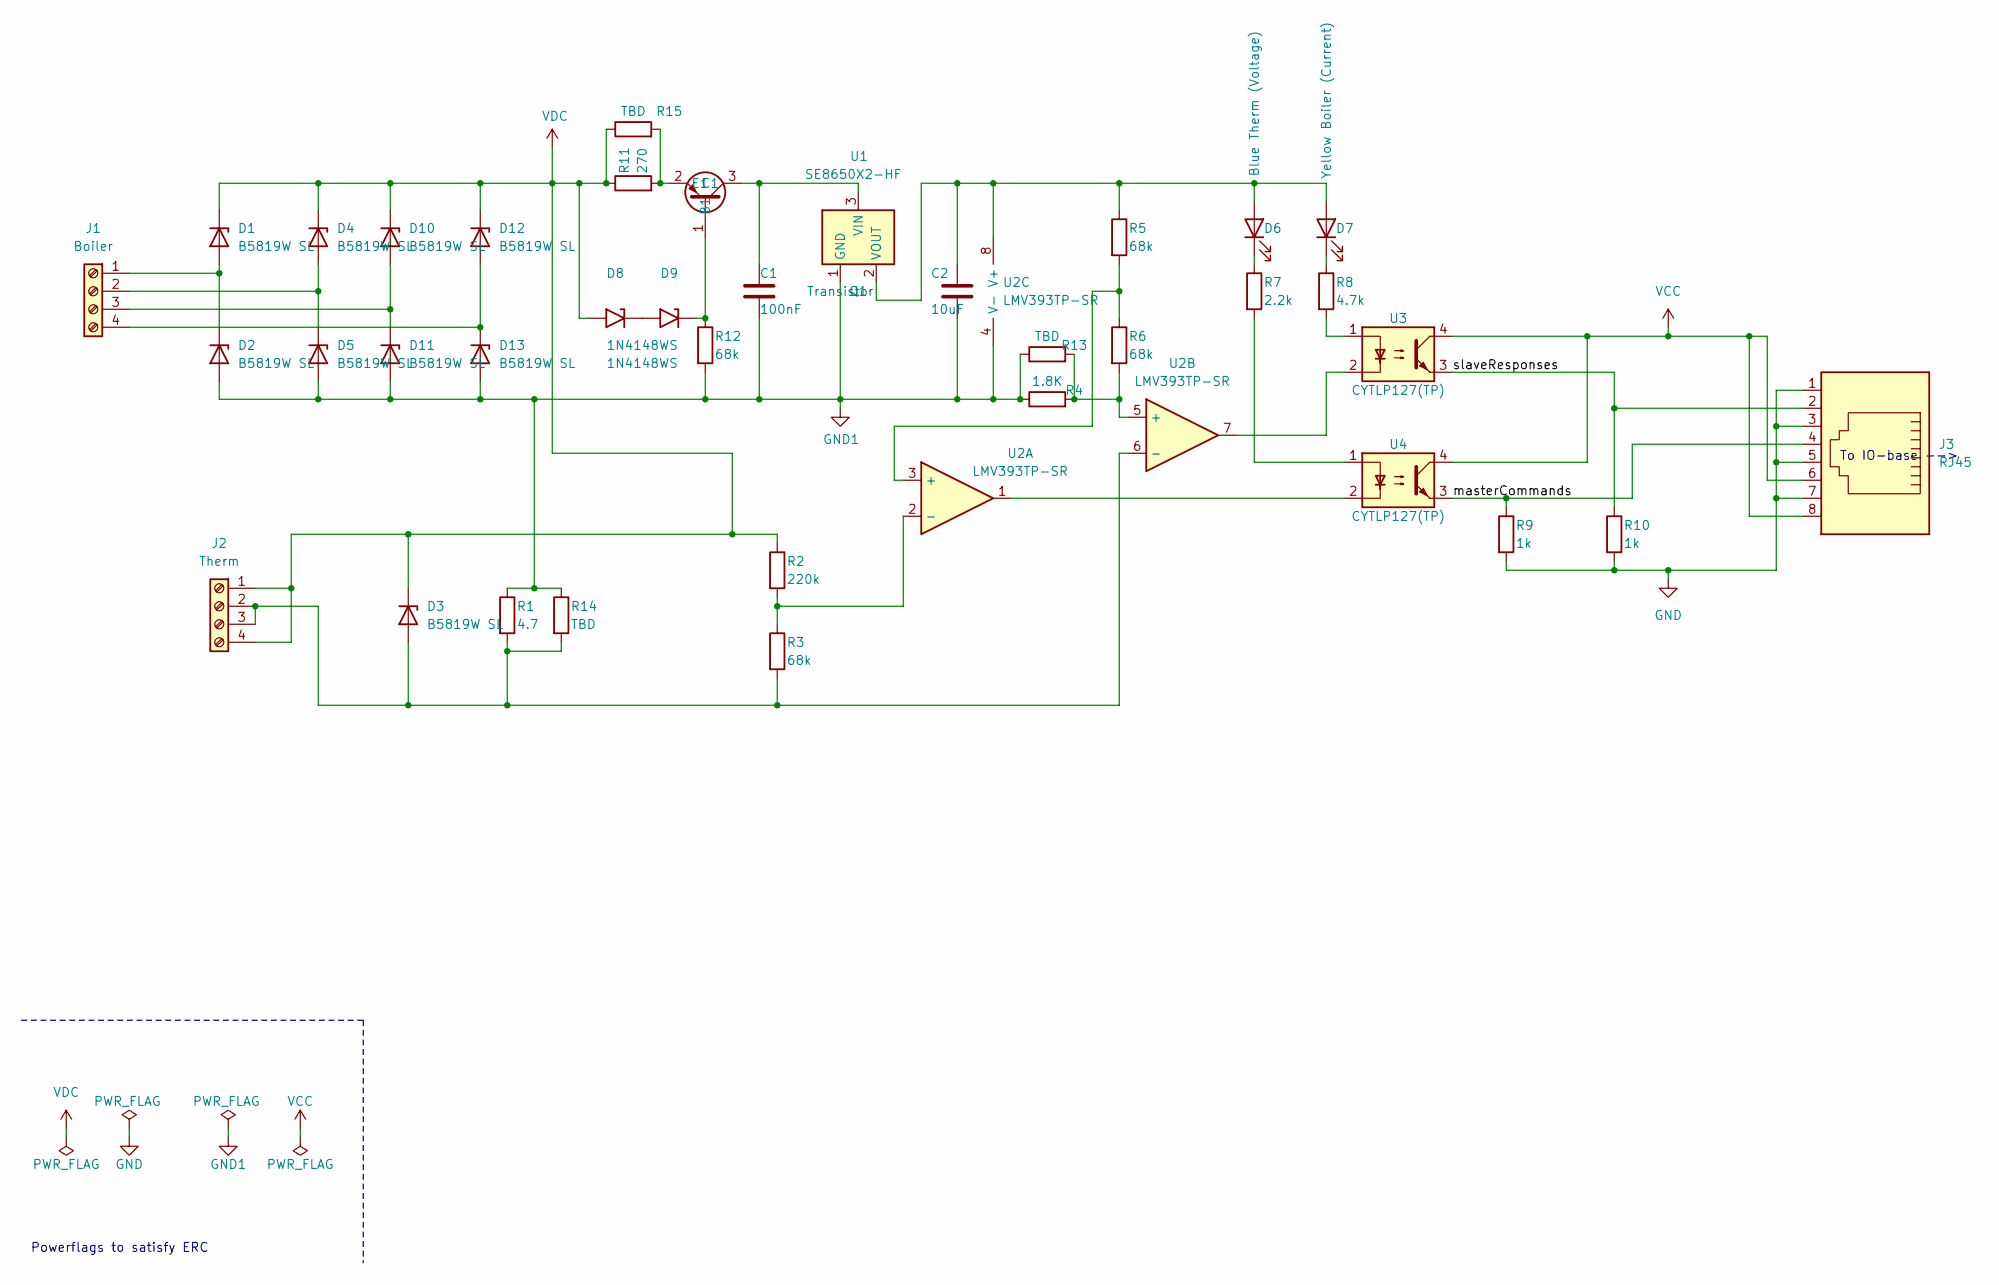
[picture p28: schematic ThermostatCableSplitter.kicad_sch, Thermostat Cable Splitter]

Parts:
C1: 100nF; C_0805_2012Metric
C2: 10uF; C_0805_2012Metric
D1, D2, D3, D4, D5, D10, D11, D12, D13: B5819W SL; D_SOD-123; LCSC C8598
D6: Blue Therm (Voltage); LED_0603_1608Metric
D7: Yellow Boiler (Current); LED_0603_1608Metric
D8, D9: 1N4148WS; D_SOD-323_HandSoldering; LCSC C2128
J1: Boiler; PhoenixContact_MSTBA_2,5_4-G-5,08_1x04_P5.08mm_Horizontal
J2: Therm; PhoenixContact_MSTBA_2,5_4-G-5,08_1x04_P5.08mm_Horizontal
J3: RJ45; RJ45_Amphenol_54602-x08_Horizontal; Mouser SS90000001
Q1: Transistor; SOT-23; LCSC C2149
R1: 4.7; R_0603_1608Metric
R2: 220k; R_0603_1608Metric
R3, R5, R6, R12: 68k; R_0603_1608Metric
R4: 1.8K; R_0603_1608Metric
R7: 2.2k; R_0603_1608Metric
R8: 4.7k; R_0603_1608Metric
R9, R10: 1k; R_0603_1608Metric
R11: 270; R_0603_1608Metric
R13, R14, R15: TBD; R_0805_2012Metric_Pad1.20x1.40mm_HandSolder
U1: SE8650X2-HF; SOT-23; LCSC C496615
U2: LMV393TP-SR; SOIC-8_3.9x4.9mm_P1.27mm; LCSC C97672
U3, U4: CYTLP127(TP); SO-4_4.4x3.6mm_P2.54mm; LCSC C2836429

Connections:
/masterCommands: J3.4, R9.1, U4.3
/slaveResponses: J3.2, R10.1, U3.3
GND: J3.1, J3.3, J3.5, J3.7, R9.2, R10.2
GND1: C1.2, C2.2, D2.2 (A), D5.2 (A), D11.2 (A), D13.2 (A), R1.1, R4.1, R12.2, R13.1, R14.1, U1.1 (GND), U2.4 (V-)
unnamed: D1.2 (A), D2.1 (K), J1.1
unnamed: D3.2 (A), J2.2, J2.3, R1.2, R3.2, R14.2, U2.6 (-)
unnamed: D4.2 (A), D5.1 (K), J1.2
unnamed: C2.1, D6.2 (A), D7.2 (A), R5.1, U1.2 (VOUT), U2.8 (V+)
unnamed: D6.1 (K), R7.1
unnamed: D7.1 (K), R8.1
unnamed: D8.1 (A1), D9.2 (A2)
unnamed: D9.1 (A1), Q1.1 (B1), R12.1
unnamed: D10.2 (A), D11.1 (K), J1.3
unnamed: D12.2 (A), D13.1 (K), J1.4
unnamed: C1.1, Q1.3 (C1), U1.3 (VIN)
unnamed: Q1.2 (E1), R11.2, R15.2
unnamed: R7.2, U4.1
unnamed: R8.2, U3.1
unnamed: U2.1, U4.2
unnamed: U2.7, U3.2
unnamed: R5.2, R6.1, U2.3 (+)
unnamed: R2.2, R3.1, U2.2 (-)
unnamed: R4.2, R6.2, R13.2, U2.5 (+)
VCC: J3.6, J3.8, U3.4, U4.4
VDC: D1.1 (K), D3.1 (K), D4.1 (K), D8.2 (A2), D10.1 (K), D12.1 (K), J2.1, J2.4, R2.1, R11.1, R15.1

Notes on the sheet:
Powerflags to satisfy ERC
To IO-base -->

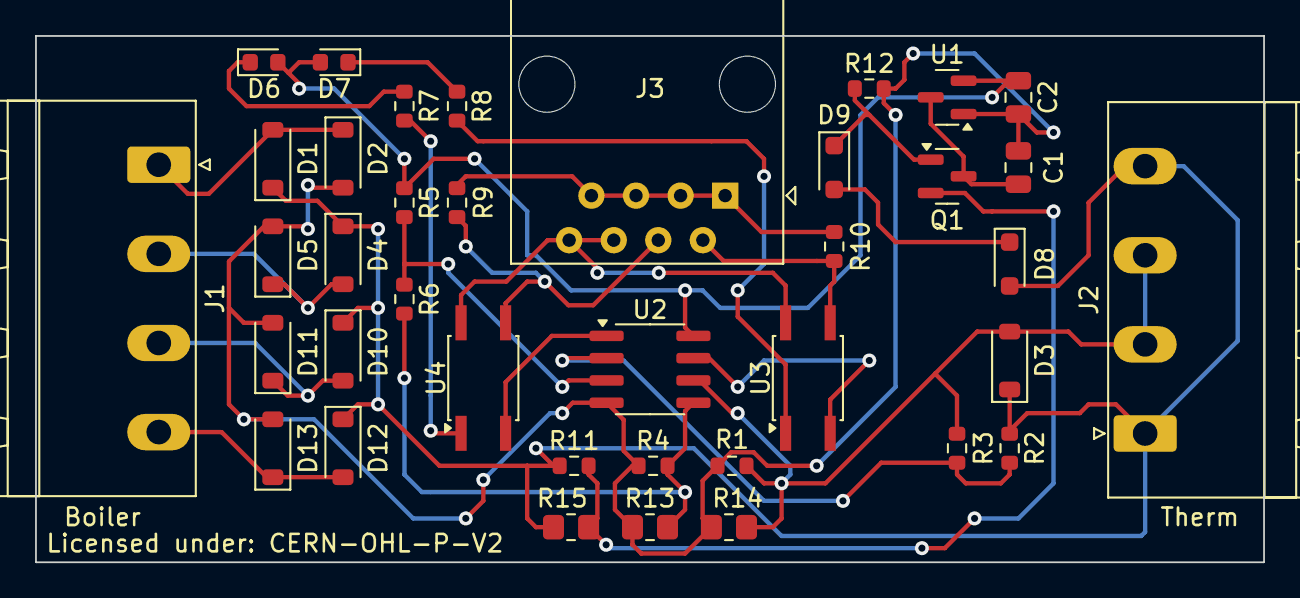
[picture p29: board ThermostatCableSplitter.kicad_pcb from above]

Board: 2 copper layers, 70.0 x 30.0 mm, 38 parts (0 on the bottom side), 25 nets.

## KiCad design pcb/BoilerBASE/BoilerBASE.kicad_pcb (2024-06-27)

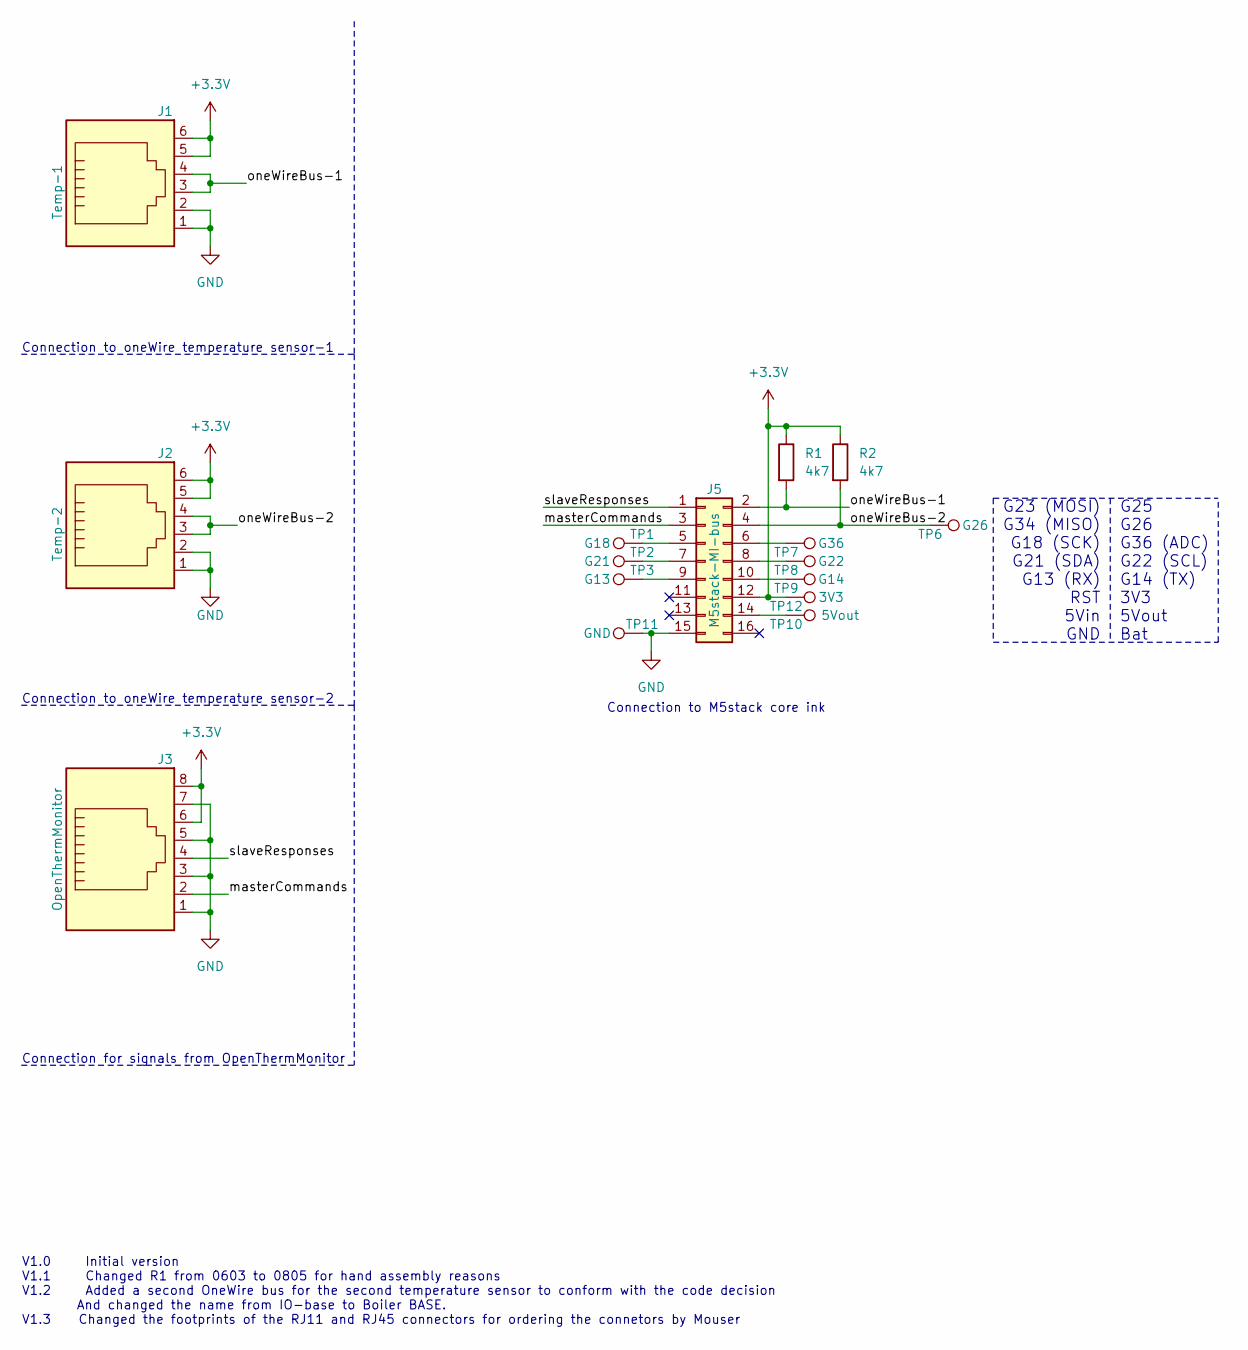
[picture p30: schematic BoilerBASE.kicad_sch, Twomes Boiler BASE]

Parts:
J1: Temp-1; RJ11 Stewart SS90000003
J2: Temp-2; RJ11 Stewart SS90000003
J3: OpenThermMonitor; RJ45 Stewart SS90000001
J5: M5stack-MI-bus; PinHeader_2x08_P2.54mm_Vertical
R1, R2: 4k7; R_0805_2012Metric_Pad1.20x1.40mm_HandSolder
TP1: G18; TestPoint_Pad_3.0x3.0mm
TP2: G21; TestPoint_Pad_3.0x3.0mm
TP3: G13; TestPoint_Pad_3.0x3.0mm
TP6: G26; TestPoint_Pad_3.0x3.0mm
TP7: G36; TestPoint_Pad_3.0x3.0mm
TP8: G22; TestPoint_Pad_3.0x3.0mm
TP9: G14; TestPoint_Pad_3.0x3.0mm
TP10: 5Vout; TestPoint_Pad_3.0x3.0mm
TP11: GND; TestPoint_Pad_3.0x3.0mm
TP12: 3V3; TestPoint_Pad_3.0x3.0mm

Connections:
+3.3V: J1.5, J1.6, J2.5, J2.6, J3.6, J3.8, J5.12, R1.1, R2.1, TP12.1
/masterCommands: J3.2, J5.3
/oneWireBus-1: J1.3, J1.4, J5.2, R1.2
/oneWireBus-2: J2.3, J2.4, J5.4, R2.2, TP6.1
/slaveResponses: J3.4, J5.1
GND: J1.1, J1.2, J2.1, J2.2, J3.1, J3.3, J3.5, J3.7, J5.15, TP11.1
unnamed: J5.5, TP1.1
unnamed: J5.6, TP7.1
unnamed: J5.7, TP2.1
unnamed: J5.8, TP8.1
unnamed: J5.9, TP3.1
unnamed: J5.10, TP9.1
unnamed: J5.14, TP10.1

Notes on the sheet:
Connection to M5stack core ink
G25 G26 G36 (ADC) G22 (SCL) G14 (TX) 3V3 5Vout Bat
Connection for signals from OpenThermMonitor
G23 (MOSI) G34 (MISO) G18 (SCK) G21 (SDA) G13 (RX) RST 5Vin GND
V1.0 Initial version V1.1 Changed R1 from 0603 to 0805 for hand assembly reasons V1.2 Added a second OneWire bus for the second temperature sensor to conform with the code decision And changed the name from IO-base to Boiler BASE. V1.3 Changed the footprints of the RJ11 and RJ45 connectors for orde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
Connection to oneWire temperature sensor-2
Connection to oneWire temperature sensor-1

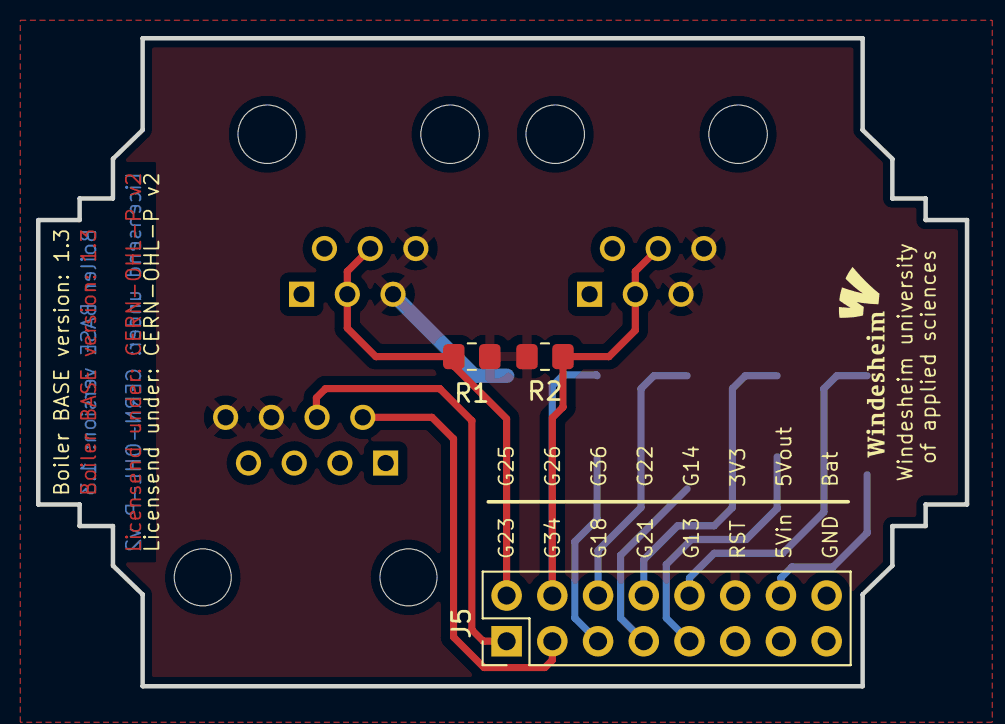
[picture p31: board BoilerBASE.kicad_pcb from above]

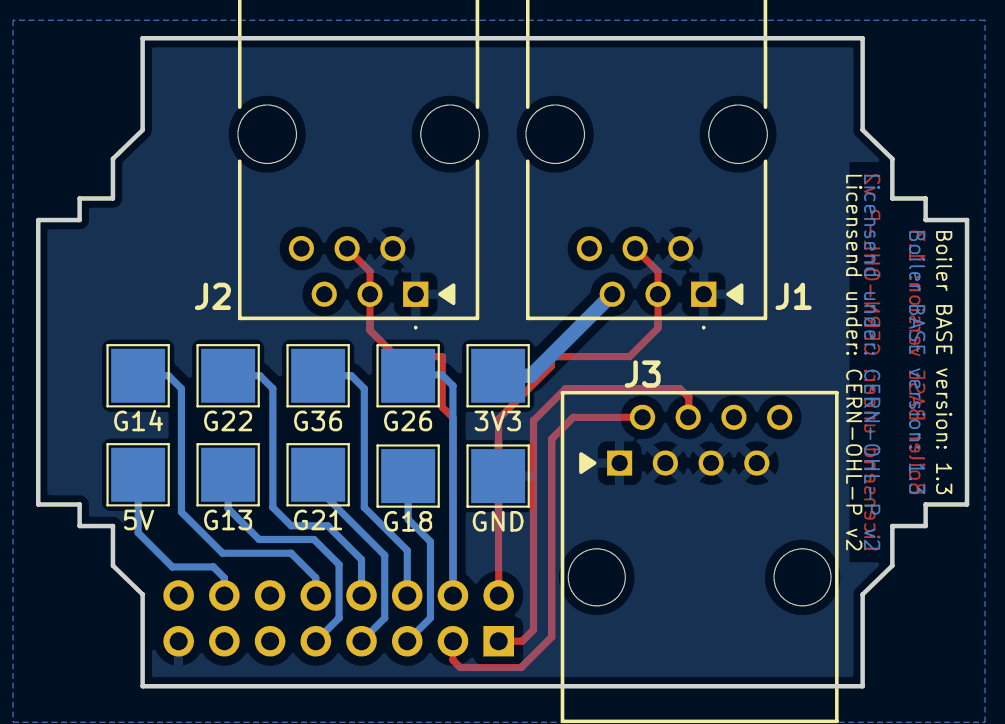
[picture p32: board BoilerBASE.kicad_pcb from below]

Board: 2 copper layers, 51.6 x 36.0 mm, 16 parts (13 on the bottom side), 13 nets.

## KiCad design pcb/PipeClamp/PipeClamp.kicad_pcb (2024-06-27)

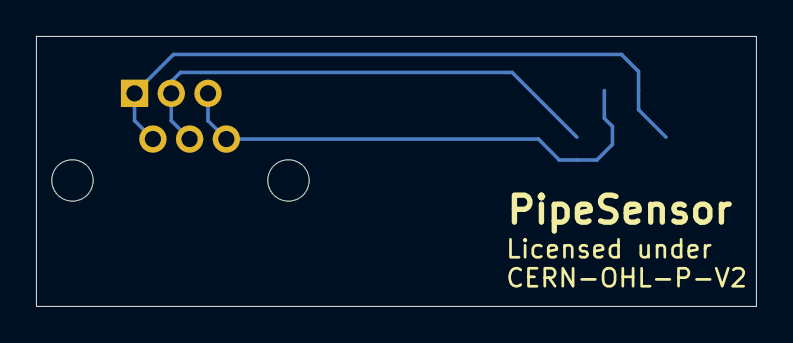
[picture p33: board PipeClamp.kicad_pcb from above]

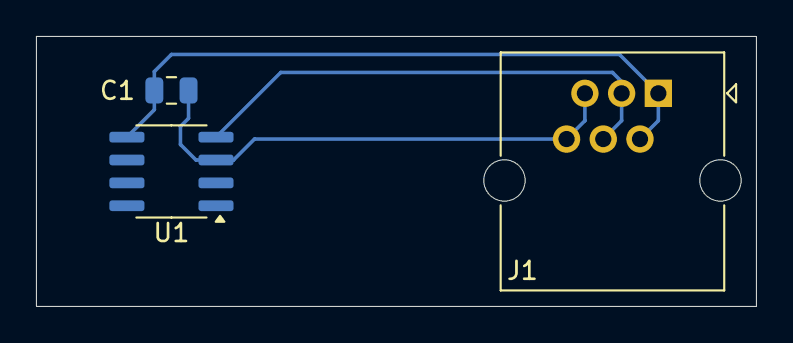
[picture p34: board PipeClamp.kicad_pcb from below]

Board: 2 copper layers, 40.0 x 15.0 mm, 3 parts (3 on the bottom side), 3 nets.

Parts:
C1: 100nF; C_0805_2012Metric
J1: RJ12; RJ25_Wayconn_MJEA-660X1_Horizontal
U1: DS18B20Z; SOIC-8_3.9x4.9mm_P1.27mm

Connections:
/GND-U1: C1.2, J1.1, J1.2, U1.5 (GND)
/VCC-U1: C1.1, J1.5, J1.6, U1.3 (V_{DD})
unnamed: J1.3, J1.4, U1.4 (DQ)

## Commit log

2023-01-19 Boiler Base intial commit: schematic, pcb, enclosure, bom, gerbers
    [Boiler_Base_case_stl_v2.STL, bom.csv, designators.csv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]
2023-01-20 added the schematics, pcb, enclosure, bom and gerbers of the OpenThermSplitter
    [Assembly.SLDASM, Bottom.SLDPRT, Bottom.STL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]
2024-06-19 New foto's for 4 cable splitter
2024-06-19 Schematics and PCBS commit to docs
2024-06-19 PCB and Schematics
2024-06-19 STL files for pipeclamps
    [Pipeclamp lock.stl, Pipeclamp.stl]
2024-06-19 STL bestanden
    [Pipeclamp lock.stl, Pipeclamp.stl]
2024-06-19 obj files
    [Pipeclamp lock.obj, Pipeclamp_.obj]
2024-06-19 Gerber file added
2024-06-19 BOM CPL files added
    [BOM-NFH PipeSensors.csv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]
2024-06-19 Name change
    [BOM-NFH PipeSensors.csv, BOM-NFHBoilerMonitor.csv, Pipeclamp lock.obj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]
2024-06-24 aligned README and repo structure with other (future) hardware repos
    [BOM-BoilerBASE.csv, BOM-NFH PipeSensors.csv, BOM-NFHBoilerMonitor.csv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]
2024-06-24 found old BoilerBASE sources again and added them, together with credits
    [Assembly.SLDASM, BOM-BoilerBASE.csv, BoilerBASE.FCStd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]
2024-06-24 BoilerBASE improvements
    [BOM-BoilerBASE.csv]
2024-06-26 reorganized jlcpcb file locations and updated cost estimate
    [BOM-BoilerBASE.csv, BOM-PipeClamp.csv, BOM-ThermostatCableSplitter.csv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]
2024-06-27 update to to for BoilerBASE BOM and CPL
2025-08-28 update PCB photos
2025-08-28 smaller pcb photos
2025-08-28 larger pcb photos, side by side
2025-08-28 add lock to enclosure photos

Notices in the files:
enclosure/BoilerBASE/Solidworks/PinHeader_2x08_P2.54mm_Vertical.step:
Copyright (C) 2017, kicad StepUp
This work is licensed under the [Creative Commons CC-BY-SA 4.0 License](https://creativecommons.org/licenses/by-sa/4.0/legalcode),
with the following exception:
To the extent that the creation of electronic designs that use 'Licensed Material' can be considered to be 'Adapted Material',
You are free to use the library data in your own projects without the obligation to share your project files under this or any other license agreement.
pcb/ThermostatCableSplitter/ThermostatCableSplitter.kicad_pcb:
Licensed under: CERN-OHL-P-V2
